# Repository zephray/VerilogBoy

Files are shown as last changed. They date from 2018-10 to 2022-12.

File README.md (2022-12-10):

VerilogBoy
==========

Coding for fun - the hard way. Trying to implement a Game Boy® compatible machine with Verilog.

This project is an open source Game Boy® compatible console Verilog RTL implementation.

# System Architecture

The main system architecture is designed as follows (outdated):

Architecture

There are three major parts needs to be implemented: the Game Boy CPU (8-bit CISC Processor called SM83, Intel 8080 like), the PPU (Pixel Processing Unit), and the sound unit (sometimes referred as a PSG, Programmable Sound Generator). Several interfacing modules are needed to support the IO capability provided by the hardware (such as an FPGA development board).

# Targets (Ports)

Current Pano Logic G1 is the only supported platform.

# Progress

Refactoring in progress. Current version could run several commerical games with no noticable glitch on the Pano Logic G1 device. 'Master' branch contains the previous version that runs on the ML505.

 - [x] SM83 CPU (Refactoring stage 1 done, passes all Blargg's tests)
 - [x] PPU (Pixel Processing Unit, Pixel-FIFO architecture)
 - [x] OAMDMA (Object Attribute Memory DMA)
 - [x] PSG (Programmable Sound Generator)
 - [x] Timer
 - [x] Link (Dummy link module, allows some games to run in single player mode)

Next step would be improving the accuracy.

Photo of VerilogBoy on Pano G1 running open source GameBoy game [Tobu Tobu Girl](http://tangramgames.dk/tobutobugirl/):

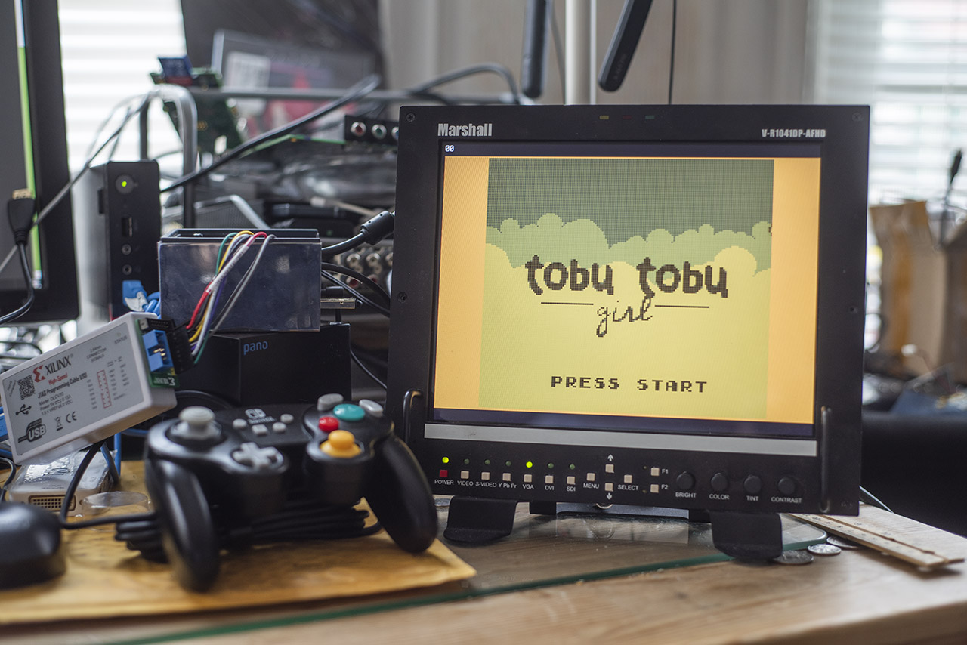
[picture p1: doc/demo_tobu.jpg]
Running-on-PanoG1


For progress regarding different ports, view README.md under the specific target folder.

# Accuracy

This project is not built to be entirely accurate, but built with accuracy in mind. Most of the CPU timing should follow the original DMG-CPU, and implement a rudimentary 2-stage pipelining just as the original one does. 

Here are the results of several tests I have tried to run on it.

PPU implementation is ... wrong: There are two pipelines in the GameBoy PPU, one for BG and one for sprite. I only implemented one for both. There is only one fetcher, though.

Note: Tests which depends on the revision / model of GameBoy are omitted. VerilogBoy only focus on behaviors that are common among all monochrome GameBoys (GS).

## Blargg's tests

| Test | mooneye-gb | BGB  | Gambatte | Higan | MESS | VerilogBoy |
| --- | --- | ---- | --- | ----- | ---- |---|
| cpu instrs | :+1: | :+1: | :+1: | :+1:  | :+1: | :+1: |

Notes: other tests hasn't been tried.

## Mooneye GB acceptance tests

| Test | mooneye-gb | BGB  | Gambatte | Higan  | MESS | VerilogBoy |
| --- | --- | ---- | --- | --- | ---- |---|
| add sp e timing | :+1: | :x:  | :+1: | :+1: | :+1: | :+1: |
| call timing | :+1: | :x:  | :+1: | :+1: | :+1: | :+1: |
| call timing2 | :+1: | :x:  | :+1: | :+1: | :+1: | :+1: |
| call cc_timing | :+1: | :x:  | :+1: | :+1: | :+1: | :+1: |
| call cc_timing2 | :+1: | :x:  | :+1: | :+1: | :+1: | :+1: |
| di timing GS | :+1: | :+1: | :+1: | :+1: | :+1: | :+1: |
| div timing | :+1: | :+1: | :+1: | :+1: | :+1: | :+1: |
| ei sequence | :+1: | :+1: | :+1: | :+1: | :x:  | :+1: |
| ei timing | :+1: | :+1: | :+1: | :+1: | :+1: | :+1: |
| halt ime0 ei | :+1: | :+1: | :+1: | :+1: | :+1: | :+1: |
| halt ime0 nointr_timing | :+1: | :+1: | :+1: | :+1: | :+1: | :+1: |
| halt ime1 timing | :+1: | :+1: | :+1: | :+1: | :+1: | :+1: |
| halt ime1 timing2 GS | :+1: | :+1: | :+1: | :+1: | :+1: | :+1: |
| if ie registers | :+1: | :+1: | :+1: | :+1: | :+1: | :+1: |
| intr timing | :+1: | :+1: | :+1: | :+1: | :+1: | :+1: |
| jp timing | :+1: | :x:  | :+1: | :+1: | :+1: | :+1: |
| jp cc timing | :+1: | :x:  | :+1: | :+1: | :+1: | :+1: |
| ld hl sp e timing | :+1: | :x:  | :+1: | :+1: | :+1: | :+1: |
| oam dma_restart | :+1: | :x:  | :+1: | :+1: | :+1: | :+1: |
| oam dma start | :+1: | :x:  | :+1: | :+1: | :+1: | :+1: |
| oam dma timing | :+1: | :x:  | :+1: | :+1: | :+1: | :+1: |
| pop timing | :+1: | :x:  | :+1: | :+1: | :+1: | :+1: |
| push timing | :+1: | :x:  | :x: | :+1: | :+1: | :+1: |
| rapid di ei | :+1: | :+1: | :+1: | :+1: | :+1: | :+1: |
| ret timing | :+1: | :x:  | :+1: | :+1: | :+1: | :+1: |
| ret cc timing | :+1: | :x:  | :+1: | :+1: | :+1: | :+1: |
| reti timing | :+1: | :x:  | :+1: | :+1: | :+1: | :+1: |
| reti intr timing | :+1: | :+1: | :+1: | :+1: | :+1: | :+1: |
| rst timing | :+1: | :x:  | :x: | :+1: | :+1: | :+1: |

### Instructions

| Test | mooneye-gb | BGB  | Gambatte | Higan  | MESS | VerilogBoy |
| --- | --- | ---- | --- | --- | ---- |---|
| daa | :+1: | :+1: | :+1: | :+1: | :+1: | :+1: |

### Interrupt handling

| Test | mooneye-gb | BGB  | Gambatte | Higan  | MESS | VerilogBoy |
| --- | --- | ---- | --- | --- | ---- |---|
| ie push | :+1: | :x:  | :x: | :x: | :x:  | :+1: |

### OAM DMA

| Test | mooneye-gb | BGB  | Gambatte | Higan  | MESS | VerilogBoy |
| --- | --- | ---- | --- | --- | ---- |---|
| basic | :+1: | :+1: | :+1: | :+1: | :+1: | :+1: |
| reg_read | :+1: | :+1: | :+1: | :x: | :x:  | :+1: |
| sources dmgABCmgbS | :+1: | :+1: | :x: | :x: | :x:  | :x: |

### Serial

| Test | mooneye-gb | BGB  | Gambatte | Higan | MESS | VerilogBoy |
| --- | --- | ---- | --- | ---| ---- |---|
| boot sclk align dmgABCmgb | :x: | :+1: | :+1: | :x: | :x:  | :x: |

Note: this test only seems to test the time to finish the first transfer. What about the second? (Delta time required to do a transfer and get notified by the interrupt)

### PPU

| Test | mooneye-gb | BGB  | Gambatte | Higan | MESS | VerilogBoy |
| --- | --- | ---- | --- | ---| ---- |---|
| hblank ly scx timing GS | :+1: | :+1: | :x: | :x: | :+1: | :x: |
| intr 1 2 timing GS | :+1: | :+1: | :+1: | :+1:  | :+1: | :x: |
| intr 2 0 timing | :+1: | :+1: | :x: | :+1:  | :+1: | :x: |
| intr 2 mode0 timing | :+1: | :+1: | :x: | :x: | :+1: | :x: |
| intr 2 mode3 timing | :+1: | :+1: | :x: | :x: | :+1: | :x: |
| intr 2 oam ok timing | :+1: | :+1: | :x: | :x: | :+1: | :x: |
| intr 2 mode0 timing sprites | :x: | :+1: | :x: | :x: | :+1: | :x: |
| lcdon timing dmgABCmgbS | :x: | :+1: | :x: | :x: | :x:  | :x: |
| lcdon write timing GS | :x: | :+1: | :x: | :x: | :x:  | :x: |
| stat irq blocking | :x: | :+1: | :+1: | :x: | :+1: | :x: |
| stat lyc onoff | :x: | :+1: | :x: | :x: | :x:  | :x: |
| vblank stat intr GS | :+1: | :+1: | :x: | :+1:  | :+1: | :x: |

### Timer

| Test | mooneye-gb | BGB  | Gambatte | Higan  | MESS | VerilogBoy |
| --- | --- | ---- | --- | --- | ---- |---|
| div write | :+1: | :+1: | :x: | :+1: | :+1: | :+1: |
| rapid toggle | :+1: | :+1: | :x: | :x: | :+1: | :+1: |
| tim00 div trigger | :+1: | :+1: | :+1: | :x: | :+1: | :+1: |
| tim00 | :+1: | :+1: | :x: | :+1: | :+1: | :+1: |
| tim01 div trigger | :+1: | :+1: | :x: | :x: | :+1: | :+1: |
| tim01 | :+1: | :+1: | :+1: | :+1: | :+1: | :+1: |
| tim10 div trigger | :+1: | :+1: | :x: | :x: | :+1: | :+1: |
| tim10 | :+1: | :+1: | :x: | :+1: | :+1: | :+1: |
| tim11 div trigger | :+1: | :+1: | :x: | :x: | :+1: | :+1: |
| tim11 | :+1: | :+1: | :x: | :+1: | :+1: | :+1: |
| tima reload | :+1: | :+1: | :x: | :x: | :+1: | :+1: |
| tima write reloading | :+1: | :+1: | :x: | :x: | :+1: | :+1: |
| tma write reloading  | :+1: | :+1: | :x: | :x: | :+1: | :+1: |

# Directory Structure

Note: things that will be removed in the near future may not shown here. Not all source files are shown here.

```
.
├── doc                          -- Documents
│   ├── control_unit.ods           -- CPU control unit LUT
│   ├── cpu_internal.md            -- CPU internal signal encoding
│   └── cpu.md                     -- CPU design note
├── LICENSE                      -- OHDL
├── Makefile                     -- Toplevel Makefile
├── README.md                    -- This document
├── roms                         -- Place for platform independent ROMs
│   ├── bootrom.s                  -- Boot ROM
│   ├── Makefile                   -- Makefile for building the Boot ROM
│   └── tests                      -- Unit tests
│       ├── compare.sh               -- Script for comparing results between VBC and emulator
│       ├── dmg_emu.exe              -- Reference emulator
│       └── Makefile                 -- Makefile for running tests
├── rtl                          -- RTL files
│   ├── alu.v                      -- ALU
│   ├── boy.v                      -- VerilogBoy portable top level file
│   ├── brom.v                     -- Boot ROM
│   ├── common.v                   -- Common definitions
│   ├── control.v                  -- Control Unit
│   ├── cpu.v                      -- CPU top level
│   ├── dma.v                      -- OAM DMA
│   ├── Makefile                   -- Makefile for building the VBC using Verilator
│   ├── mbc5.v                     -- Cartridge paging, optional
│   ├── ppu.v                      -- Pixel Processing Unit
│   ├── regfile.v                  -- CPU Register file
│   ├── singleport_ram.v           -- Singleport RAM template
│   ├── singlereg.v                -- Singlebit register template
│   └── timer.v                    -- Timer
├── sim                          -- Simualtion
│   └── verilator                  -- Verilator-based simulator 
│       ├── dispsim.cpp              -- LCD simulator based on SDL 2.0
│       ├── Makefile                 -- Makefile for building the simulator
│       ├── mbcsim.cpp               -- MBC cartridge controller simulator
│       ├── memsim.cpp               -- Boot ROM or Game ROM simulator
│       ├── mmrprobe.cpp             -- Unit for dumping memory or MMR accesses
│       └── vb_sim.cpp               -- Simulator main file
├── target                       -- Targets (ports) of VBC
│   ├── panog1                     -- Pano Logic G1 devices
│   │   ├── fpga                     -- FPGA RTL
│   │   │   ├── dualport_ram.v         -- Template of dual port RAM
│   │   │   ├── idt_clkgen.v           -- Code for interfacing with clock generator
│   │   │   ├── mig                    -- LPDDR memory controller
│   │   │   ├── mig_picorv_bridge.v    -- Bridge for connecting PicoRV32 and LPDDR controller
│   │   │   ├── mig.ucf                -- Timing constraint for memory controller
│   │   │   ├── mobile_ddr.v           -- Simulation model for LPDDR
│   │   │   ├── panog1.xise            -- ISE project file
│   │   │   ├── pano_top.v             -- Top level HDL
│   │   │   ├── pano.ucf               -- Main pin location constraint
│   │   │   ├── picorv32.v             -- PicoRV32 RISC-V softcore
│   │   │   ├── picosoc_mem.v          -- PicoRV32 scratchpad memory
│   │   │   ├── simple_uart.v          -- Simple UART transmitter 
│   │   │   ├── testbench.v            -- Testbench with LPDDR model
│   │   │   ├── usb_picorv_bridge.v    -- Bridge for connecting PicoRV32 and USB controller
│   │   │   ├── vga_font.v             -- VGA font ROM
│   │   │   ├── vga_mixer.v            -- Mixing PicoRV32 and VerilogBoy image
│   │   │   └── vga_timing.v           -- VGA timing generator
│   │   ├── fw                       -- Firmware for RV softcore
│   │   │   ├── bootloader             -- Bootloader for loading firmware from SPI Flash
│   │   │   │   ├── bootloader.c         -- Main source code
│   │   │   │   ├── Makefile             -- Makefile for building the bootloader
│   │   │   │   ├── sections_bl.lds      -- Link script
│   │   │   │   └── start_bl.s           -- Startup code
│   │   │   ├── dhrystone              -- Dhrystone test for RV softcore
│   │   │   ├── firmware               -- Firmware for softcore
│   │   │   │   ├── COPYING              -- GPLv2 License for firmware
│   │   │   │   ├── firmware.c           -- Main source code 
│   │   │   │   ├── isp1760.c            -- ISP1760 HCD
│   │   │   │   ├── isp_roothub.h        -- RootHub emulation for HCD (optional)
│   │   │   │   ├── Makefile             -- Makefile for building the firmware
│   │   │   │   ├── misc.c               -- Delay and other common routines
│   │   │   │   ├── sections.lds         -- Link script
│   │   │   │   ├── syscalls.c           -- Syscalls for the newlib
│   │   │   │   ├── term.c               -- Simple virtual terminal
│   │   │   │   ├── usb.c                -- Host USB stack
│   │   │   │   ├── usb_gamepad.c        -- Generic USB HIB gamepad driver
│   │   │   │   └── usb_storage.c        -- USB mass storage driver
│   │   │   └── README.md              -- README about firmware
│   │   └── README.md                -- README about Pano Logic G1 port
│   └── vbh                        -- VerilogBoy Handheld
│       ├── fpga                     -- FPGA RTL
│       └── fw                       -- Firmware for on-board MCU
└── tools                        -- Tools for building things
    ├── bin2mif                    -- Convert binary blob to mif
    └── vga_timing.xlsx            -- Tool for calculating VGA timing
```

# How to use

## Verilator-based simulator

Tested environment: Ubuntu 20.04 LTS, mac OS Big Sur. 

Dependencies: build-essential, verilator, libsdl2-dev, wine(optional, for unit test only, for now), rgbds(not available from apt, need build manually).

On Debian/ Ubuntu, do the following:

```
sudo apt install build-essential verilator libsdl2-dev wine byacc flex pkg-config libpng-dev
```

On macOS, do the following:

```
brew install verilator sdl2 pkg-config libpng
```

To install rgbds:

```
git clone https://github.com/rednex/rgbds
cd rgbds
make
make install
```

### Build

At project directory:
```
make
```

Copy the bootrom.mif to where it is required. (For example, target/panog1)

### Running unit-tests

At project directory:
```
cd roms/tests
make
./compare.sh
```

### Running ROMs

At project directory:
```
./sim/verilator/vb_sim <path_to_your_rom.gb> --mbc --nostop
```

Few parameters:
```
--nostop: Don't stop execution at halt/stop (but stop at illegal instructions)
--trace: Generate vcd waveform trace
--testmode: Disable internal Boot ROM, headless mode, limit cycles to 32K.
--noboot: Disable internal Boot ROM, code execution starts at 0x0000 rather than 0x0100.
--verbose: Enable debug output
--mbc: Enable MBC1/3/5 emulation for ROMs larger than 32KB
```

## FPGA targets

See README inside target directory.

# Acknowledge

This project reused codes from several other projects. A great thanks to their efforts!

 - [https://github.com/nightslide7/Gameboy](https://github.com/nightslide7/Gameboy)
 - [https://github.com/cliffordwolf/picorv32](https://github.com/cliffordwolf/picorv32)
 - [https://github.com/u-boot/u-boot](https://github.com/u-boot/u-boot)
 - [https://github.com/twlostow/dsi-shield](https://github.com/twlostow/dsi-shield)
 - [https://github.com/MParygin/v.vga.font8x16](https://github.com/MParygin/v.vga.font8x16)

These projects are used as references. Again, thanks for sharing.

 - [https://github.com/freecores/genesys_ddr2](https://github.com/freecores/genesys_ddr2)
 - [https://github.com/ZipCPU/s6soc](https://github.com/ZipCPU/s6soc)

These are extremely helpful resources about the Game Boy® itself:

 - [https://github.com/Gekkio/mooneye-gb](https://github.com/Gekkio/gb-ctr)
 - [https://github.com/Gekkio/gb-ctr](https://github.com/Gekkio/gb-ctr)

Game used for demonstration, thanks for the great game:

 - [https://github.com/SimonLarsen/tobutobugirl](https://github.com/SimonLarsen/tobutobugirl)

# Legalese

I'm not affiliated with Nintendo in any way. Game Boy® is a registered trademark by Nintendo. Nintendo® is a registered trademark. All other trademarks are property of their respective owner.

# License

The dsicore is made by twlostow, released under LGPL 3.0.

The PicoRV32 is free and open hardware licensed under the [ISC license](http://en.wikipedia.org/wiki/ISC_license)
(a license that is similar in terms to the MIT license or the 2-clause BSD license).

Some firmware code of pano-g1 target are released to public domain.

All other software codes (including simulation code) are licensed under MIT.

All other HDL codes are licensed under OHDL 1.0.

All other text documents are licensed under CC BY-SA 4.0

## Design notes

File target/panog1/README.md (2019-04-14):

VerilogBoy for Pano Logic G1
============================

## Overview

From https://tomverbeure.github.io/rtl/2018/11/26/Racing-the-Beam-Ray-Tracer.html#the-hw-platform:

> Pano Logic was a Bay Area startup that wanted to get rid of PCs in large organizations by replacing them with tiny CPU-less thin clients that were connected to a central server. Think of them as VNC replacements. No CPU? No software upgrades! No virusses!
> 
> The thin clients had a wired Ethernet interface, a couple of USB ports, an audio port and a video port.
> All this was glued together with an FPGA.
> 
> The company has been defunct since 2013 and the clients are not supported by anything. But they are amazing for hobby purposes and can be bought dirt cheap on eBay.
> 
> There are 2 versions: the first one has a VGA video interface, later versions have a DVI port.
> 
> The VGA version uses the Xilinx Spartan-3E 1600. The DVI version a very powerful Spartan-6 LX150.

This port focus on the VGA version (3E-1600).

## Status

Working in Progress. Preview version available in the GitHub 'Releases' section.

## Components

### LPDDR controller

Based on Xilinx MIG, LPDDR-200 @ 16-bits.

Details available at hackaday: [A detour to the Pano Logic G1 (1) - LPDDR](https://hackaday.io/project/57660/log/159790-a-detour-to-the-pano-logic-g1-1-lpddr)

Used to be a memory cache between PicoRV32 and LPDDR, now as code is XIP from Flash, cache is move to flash. All access to LPDDR is non cached.

### PicoRV32 soft-processor

PicoRV32 is a RISC-V compatible soft-processor written by Clifford Wolf: https://github.com/cliffordwolf/picorv32.

Configured as RV32IC, running at 25MHz.

Currently, code is XIP from SPI Flash. SPI Flash also runs at 25MHz (Maximum frequency of M25P80 is 75MHz), 1 bit mode. A 4KB 2-way set associative cache is added between the PicoRV32 and SPI IF. Expect very poor performance.

The PicoRV32 uses in total 8 BRAM18K for memories, 4 as scratchpad memory (8KB), 2 as I-cache (4KB), 2 as video RAM (4KB).

## Building

A modern Linux environment is required to build the firmware for the PicoRV32 soft processor. ISE version 14.7 is required to build the bitstream for the FPGA, WebPACK version is fine. ISE doesn't need to be installed on the Linux, it can be installed on a sepearate Windows machine, or inside a virtual machine.

### Firmware

Follow the instruction in the [PicoRV32 repository](https://github.com/cliffordwolf/picorv32) to install the riscv32ic toolchain.

Cd into target/panog1/fw/firmware, run '''make'''. The firmware.bin is the target firmware.

### BootROM

A boot ROM is required to boot the VerilogBoy Core. Skip if you are not going to play GB games on it.

[rgbds](https://github.com/rednex/rgbds) is required to build the boot ROM. Follow the instruction to install it.

Cd into roms, run '''make'''. The bootrom.mif is the target firmware. Copy the file into target/panog1/fpga.

### Bitstream

Open target/panog1/fpga/panog1.xise using ISE, double click 'Generate Programming File', the pano_top.bit is the target bitstream.

### Flash Image

1. Open iMPACT, create a new project, and double click 'Create PROM File' on the left. 
2. Select 'Configure Single FPGA' under 'SPI Flash' on the left. Click the right arrow button.
3. Select '8M' as 'Storage Device (bits)', click 'Add Storage Device', and then click the right arrow button.
4. Enter a file name, set 'Add Non-Configuration Data Files' to 'Yes'. Click 'OK'.
5. Select the bitstream file. 
6. When asked to add another device file, select 'No'.
7. When asked to add data file, select 'Yes'
8. Enter 'c0000' as the start address.
9. Choose the 'firmware.bin'. (Not 'firmware.elf'!)
10. Double click 'Generate File' on the left.
11. Now the target mcs file should be generated. Flash it into the FPGA use iMPACT.

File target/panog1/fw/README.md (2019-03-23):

Firmware for Pano Logic G1
==========================

# How to use

Type '''make''' to build the firmware. Depending on the type, it may either generate a .bin file (to be flashed into SPI Flash) or some .mif file (to be loaded into Block RAM). For the .bin file, generate and flash the .mcs image use iMPACT. For the .mif file, copy over to ../fpga and rebuild the FPGA project.

# What's here

 - bootloader: Initialize the LPDDR, do a simple memory check, and copy the content from SPI Flash into LPDDR then jump to the LPDDR.
 - dhrystone: Dhrystone test, to be executed inside LPDDR. (Or withsome modification, inside BlockRAM). Typical performance inside LPDDR: 0.25 DMIPS/MHz.
 - firmware: Main firmware to be used in the project.

Generally you want to use the bootloader and the firmware.

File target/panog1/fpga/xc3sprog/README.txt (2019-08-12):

This dir contains simple cores to access the internal SPI-flash via BSCAN/USER1.

The bitfiles are provided for your convenience.

All IOBs are unused and set to float.
The config + JTAG pins have their default pull-up/downs enabled. 
You have to make your own bitstream if you don't like that.

The Spartan-3E Starterkit (ug320.pdf) can have a lot of possible
contentions. So BSCAN_SPI needs some more Pins set to work. Often the first
run with the -I option still fails. The kit also fails to reboot after some
-I run has been done.

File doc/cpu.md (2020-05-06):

# CPU

The Game Boy® is powered by a 8-bit Intel 8080-like CISC processor. It is usually called as "GB-Z80", however, it is not a Z80 compatible processor, nor a 8080 compatible processor. This page is not a full document of the original GameBoy processor, but some brief description of the processor and some of my own understanding. The information in this page may or may not be correct.

For a comprehensive and more reliable documentation of GB CPU, see https://github.com/Gekkio/gb-ctr.

## Registers

The Game Boy CPU have one bank of general purpose 8-bit registers:

* B
* C
* D
* E
* H
* L

These 8-bit registers may be accessed as 16-bit registers:

* BC
* DE
* HL

There are two SF 8-bit registers:

* A - Accumulator
* F - Flags

There are 4 usable flags in the flags register, all other bits are 0:

* 7 - Z (Zero)
* 6 - N (Substract)
* 5 - H (Half Carry)
* 4 - C (Carry)

There are also two SF 16-bit registers:

* PC - Program Counter
* SP - Stack Pointer

Since the PC is 16-bit, SP should always be 16-bit aligned. SP always point to last used stack slot. Means that the first slot should be always empty.

Note, though there are 16-bit register, and the 8-bit register may be accessed in the 16-bit manner, the internal datapath is limited to 8-bit, means it could not finish 16-bit data transfer in one cycle. These are solely for addressing.

## Instructions

Instruction length can be 1 - 4 bytes long depending on the specific instruction. Opcodes can be seen as 9 bits long, and will be encoded into 1 or 2 bytes. If the first byte is 0xCB, then the second byte would be one of the high 256 opcodes, otherwise, the first byte is one of the low 256 opcodes. 

For example, if the first byte is 0x43, then the opcode of this instruction is 0x043; if the first byte is 0xCB and the next byte is the 0x43, then the opcode of this instruction is 0x143.

After the opcode, there can be a optional immediate, 8-bit or 16-bit long, gives the total length of 1 - 4 bytes.

## Execution Timing

The processor runs at either 4 MiHz (4194304 Hz = 2^12 Hz) or 8 MiHz (Double Speed Mode on GBC). The instruction execution time is always dividable by 4, ranging from 4 cycles to 20 cycles. Ususally a clock cycle at 4 MiHz is called a T-cycle. 4 T-cycles combined together is called a M-cycle (1 MiHz). So, one instruction could take 1 - 5 M-cycles to execute. 

The processor can do one memory read or memory write in one M-cycle, since the instruction itself needed be fetched, the execution speed can never be faster than the speed it can read the instruction. For example, a 3 byte instruction needs at least 3 M-cycles (12 T-cycles) to execute. If the instruction involves memory read or write, the processor would have to spend more M-cycles just to access the memory. 

The processor is also only capable of doing 1 8-bit ALU operation each M-cycle, if the instruction need to do 16-bit ALU operation, additional 1 M-cycle may be needed to complete the operation.

The processor also has a prefetch queue with the length of 1 byte.

## Bus Timing

The GB CPU has one 8080 bus compatible bus. The bus supports only memory access, not IO access. All the ROM, RAM, and MMIO peripherals are on the same bus. Here is a timing diagram:

```text
            |  1  |  2  |  3  |  4  |
          ___________             _____            
CLK  ____|           |___________|     
    __    __    __    __    __    __    
CK    |__|  |__|  |__|  |__|  |__|  |__
    ___________                   _____
CS             |_________________|
             ____________________
RD  ________|                    |_____
    _________________       ___________
WR                   |_____|
     _______ _______________________ __
ADDR _______X_______________________X__
                      _____
DATA ----------------<_____>-----------
```

CLK: 1 MiHz Bus Reference Clock
CK:  4 MiHz Internal Clock (need to verify the phase)
ADDR: Address Bus
CS, RAM Access Enable, Low Active
RD: Read Enable, Low Active
WR, Write Enable, Low Active

Note: See GB-CTR for more information.

## Instructions

## Common Encodings

### 16bit Reg addressing encoding 1 (e_ad1)
* 2'b00: BC
* 2'b01: DE
* 2'b10: HL
* 2'b11: SP

### 16bit Reg addressing encoding 2 (e_ad2)
* 2'b00: BC
* 2'b01: DE
* 2'b10: HL+
* 2'b11: HL-

### 16bit Reg addressing encoding 3 (e_ad3)
* 2'b00: BC
* 2'b01: DE
* 2'b10: HL
* 2'b11: AF

### 8bit Reg addressing encoding 1 (e_ab1)
* 3'b000: B
* 3'b001: C
* 3'b010: D
* 3'b011: E
* 3'b100: H
* 3'b101: L
* 3'b110: databus
* 3'b111: A

### 8bit Reg addressing encoding 2 (e_ab2)
* e_ab1 with LSB moved to MSB (021)

### ALU operations (e_alu)
* 3'b000 ADD
* 3'b001 ADC
* 3'b010 SUB
* 3'b011 SBC
* 3'b100 AND
* 3'b101 XOR
* 3'b110 OR
* 3'b111 CP

### Special ALU operations (e_alu_sp)
* 2'b00 DAA
* 2'b01 CPL
* 2'b10 SCF
* 2'b11 CCF

### Bitwise ALU operations part 1 (e_alu_b1)
* 3'b000 RLC
* 3'b001 RRC
* 3'b010 RL
* 3'b011 RR
* 3'b100 SLA
* 3'b101 SRA
* 3'b110 SWAP
* 3'b111 SRL

### Bitwise ALU operations part 2 (e_alu_b2)

* 2'b00 Used by other opcodes
* 2'b01 BIT
* 2'b10 RES
* 2'b11 SET

## Load SP to Immediate Address

* LD (a16), SP
* 3 bytes long
* 5 M-cycles to execute
* No flags shall be altered
* 8'b00001000

## Load 16bit immediate to 16bit register

* LD rr, d16
* 3 bytes long
* 3 M-cycles to execute
* No flags shall be altered
* 8'b00rr0001
* Use e_ad1 for rr encoding

## Load Register to Memory

* LD (rr), A
* 1 byte long
* 2 M-cycles to execute
* No flags shall be altered
* If self increment/decrement is involved, it should happen after the access
* 8'b00dd0010
* Use e_ad2 for rr encoding

## Load 8bit Immediate to 8bit Register/ to Memory

* LD r, d8 / LD (HL), d8
* 2 bytes long
* 2 (reg)/ 3 (mem) M-cycles to execute
* No flags shall be altered
* 8'b00rrr110
* Use e_ab2 for rrr encoding

## Load Memory to Register

* LD A, (rr)
* 8'b00dd1010
* Otherwise the same as load reg to mem

## Load 8bit Register to 8bit Register/ to/ from Memory

* LD rd, rs
* 1 byte long
* 1 (reg)/ 2 (mem) M-cycles to execute
* No flags shall be altered
* 8'b01dddsss
* Use e_ab1 for ddd encoding
* Use e_ab1 for sss encoding
* Note that LD (HL), (HL) is impossible, it is replaced by HALT

## 16bit Register Self Increment/ Decrement

* INC dd / DEC dd
* 1 byte long
* 2 M-cycles to execute
* No flags shall be altered
* 8'b00dd0011 (INC) / 8'b00dd1011 (DEC)
* Use e_ad1 for dd encoding

## 8bit Register/ Memory Self Increment/ Decrement

* INC d / DEC d / INC (HL) / DEC (HL)
* 1 byte long
* 1 (reg)/ 3 (mem) M-cycles to execute
* Zero, Substract, and Half-Carry flag are altered
* 8'b00ddd100 (INC) / 8'b00ddd101 (DEC)
* Use e_ab2 for ddd encoding

## 8bit ALU Operations

* ADD r / ADC r / SUB r / SBC r / AND r / XOR r / OR r / CP r
* 1 byte (reg/mem) / 2 (imm) long
* 1 (reg) / 2 (mem) / 2 (imm) M-cycles to execute
* Flags depending on operation
* 8'b1iaaarrr
* i: 0 - Read from (HL), 1 - Use immediate value
* Use e_alu for aaa encoding
* Use e_ab1 for rrr encoding

## 8bit Special ALU Operations

* DAA / SCF / CPL / CCF
* 1 byte long
* 1 M-cycle to execute
* Flag depends
* 8'b001ss1111
* Use e_alu_sp for ss encoding

## 8bit Bitwise ALU Operations Part 1

* RLC r / RRC r / RL r / RR r / SLA r / SRA r / SWAP r / SRL r
* 1 byte long (not include CB)
* 1 (reg) / 3 (mem) to execute
* Flag depends
* 8'b00bbbrrr
* Use e_alu_b1 for bbb encoding
* Use e_ab1 for rrr encoding

## 8bit Bitwise ALU Operations Part 2

* BIT n, r / RES n, r / SET n, r
* 1 byte long (not include CB)
* 1 (reg) / 2 (memwb) / 3 (memtest) to execute
* Flags depends
* 8'bccnnnrrr
* Use e_alu_b2 for cc encoding
* Use e_ab1 for rrr encoding

## Microarchitecture

Note: This is NOT the microarchitecture of the GameBoy CPU, but that of the VerilogBoy CPU. It is a non-pipelined multi-cycle CISC core with hardwired control logic. To optimize the resource usage, the first stage decoding is actually a 256 entries LUT.

BCDEHLSP are in the register file, while A, F, and PC are not.

One M-cycle is 4 T-cycle. 

### CT-FSM

CT-FSM is a FSM running with the main 4 MiHz clock. It takes care of all the bus operations and instruction execution. It has 4 states,  always executed in a loop, from S0 to S3. To be clear, I am describing it from 2 perspectives: bus operation and instruction execution.

Bus Operation:

* S0: High Page access from last M-cycle
* S1: Setup Address
* S2: Wait
* S3: Setup Data for write cycle, Latch data for read cycle 

Instruction Execution:

* S0: Decoding & Execution
* S1: Register Write Back
* S2: PC Increment Cycle 1 / SP Operation Cycle 1
* S3: PC Increment Cycle 2 / SP Operation Cycle 2

### EX-FSM

EX-FSM is a FSM running only in S0 state in CT-FSM. The reason of having this FSM is that the CPU might need multiple M cycles to finish the execution of a single instruction, the FSM would keep track of which cycle it is in. Means the state of this FSM should always match the M cycle number.

If the instruction finishes this cycle, next cycle would be S0.

Main tasks of this FSM:
pc_wr
* Determine if this M-cycle would be memory write, memory read, or instruction fetch.
* Determine the input numbers of the ALU.
* Determine if the output of ALU should be write back to register.
* Determine if PC needs to be incremented.

Example:

ADD A, B, 1 cycle operation
During M0 - S1, EX-FSM instruct ALU OpA to be A, ALU OpB to be B, ALU Res WB En.

ADD A, (HL), 2 cycle operation

During M0 - S1, EX-FSM instruct ALU OpA to be A, ALU OpB to be Data Bus, ALU Res WB NEN, HL output to be next cycle ABUS Src, next state is S2

During M1 - S2, EX-FSM instruct ALU Res WB EN, PC output to be next cycle ABUS Src, next state is S1

```
       -----------             -----------             -----------             -----------             -----------
   ___|           |___________|           |___________|           |___________|           |___________|
      ^ S3 - Instr Fetch      ^ S0 - Control Unit     ^ S1 - Output PC low    ^ S2 - Output PC high   ^ S3 - ALU Free
                                                      ^ S1 - Output Last PC
                                                      ^ S1 - Register WB      ^ PC low WB             ^ PC high WB
```

JR:
Cycle 0: Fetch PC (JR); Calculate PC + 1
Cycle 1: JR execution, Fetching PC + 1, PC + 2 interrupted.
Cycle 2: r ready, calculate PC + r low byte
Cycle 3: calculate PC + r high byte, save to PC, and output to bus (!!!)

PUSH:
Cycle 0: Fetch PC (PUSH); Calculate PC + 1
Cycle 1: ALU: Nothing. No bus op. PC + 1 circuit use to calculate SP - 1
Cycle 2: ALU: Fetch B; DATA from Regfile; PC + 1 circuit use to calculate SP - 1
Cycle 3: ALU: Fetch C; DATA from Regfile; PC + 1 stopped.
Cycle 4: PC + 2 calculated; Fetch PC + 1;

POP:
Cycle 0: Fetch PC (POP), Calculate PC + 1
Cycle 1: ALU: Nothing. DATA Read from SP. PC + 1 circuit use to calculate SP + 1
Cycle 2: ALU: Data buffer to B; Data Read from SP. PC + 1 circuit use to calculate SP + 1
Cycle 3: ALU: Data buffer to C; Fetch PC + 1; Calculate PC + 1

LD (nn), A:
Cycle 0: Fetch PC, Calculate PC + 1
Cycle 1: ALU do nothing. Fetch PC + 1 (Imm), Calculate PC + 1
Cycle 2: ALU do nothing. Fetch PC + 1 (Imm), Stop PC calculation.
Cycle 3: ALU do nothing. Data write from A to TEMP. Stop PC calculation.
Cycle 4: ALU do nothing. Fetch PC + 1; Calculate PC + 1;

LD (nn), SP:
Cycle 0: Fetch PC, Calculate PC + 1
Cycle 1: ALU do nothing. Fetch PC + 1 (Imm), Calculate PC + 1
Cycle 2: ALU do nothing. Fetch PC + 1 (Imm), Stop PC calculation.
Cycle 3: ALU do nothing. Addr from Imm, Data write from SP to bus. Calculate Imm + 1
Cycle 4: ALU do nothing. Addr from Imm, Data write from SP to bus. 
Cycle 5: ALU do nothing. Fetch PC + 1; Calculate PC + 1;

LD A, (nn):
Cycle 0: Fetch PC, Calculate PC + 1
Cycle 1: ALU do nothing. Fetch PC + 1 (Imm), Calculate PC + 1
Cycle 2: ALU do nothing. Fetch PC + 1 (Imm), Stop PC calculation.
Cycle 3: ALU do nothing. Data read from TEMP. Stop PC calculation.
Cycle 4: ALU store data buffer to A. Fetch PC + 1; Calculate PC + 1;

RST:
Cycle 0: Fetch PC, Calculate PC + 1
Cycle 1: ALU: PCl to DB. No bus op. PC + 1 circuit use to calculate SP - 1
Cycle 2: ALU: PCh to DB; DATA from PCl to SP; PC + 1 circuit use to calculate SP - 1
Cycle 3: ALU: 16bit PC from Opcode; DATA from PCh to SP; Stop PC calculation.
Cycle 4: Fetch new PC; Calculate PC + 1

CALL nn:
Cycle 0: Fetch PC, Calculate PC + 1
Cycle 1: ALU do nothing. Fetch PC + 1 (Imm), Stop PC calculation.
Cycle 2: ALU do nothing. Fetch PC + 1 (Imm), Stop PC calculation.
Cycle 3: ALU: Nothing. No bus op. PC + 1 circuit use to calculate SP - 1
Cycle 4: ALU: Nothing; DATA from PCh to SP; PC + 1 circuit use to calculate SP - 1
Cycle 5: ALU: 16bit PC from Temp; DATA from PCl to SP; Stop PC calculation.
Cycle 6: Fetch new PC; Calculate PC + 1

RET:
Cycle 0: Fetch PC, Calculate PC + 1
Cycle 1: ALU: Nothing. Read SP. PC + 1 circuit use to calculate SP + 1
Cycle 2: ALU: Copy from Databus to PCl; Read SP + 1; PC + 1 circuit use to calculate SP + 1
Cycle 3: ALU: Copy from Databus to PCh; Databus no op. Stop PC calculation.
Cycle 4: Fetch new PC; Calculate PC + 1

RET cc:
Cycle 0: Fetch PC, Calculate PC + 1
Cycle 1: Check condition and decide if need to continue
Cycle 2: If taken, same as ret start from Cycle 1; If not, fetch new PC; Calculate PC + 1

## Interrupt

The interrupt check happens at the same time as the instruction fetch (S3). If there is an interrupt, the normal execution would be stopped, and the instruction fetch for the ISR would happen at the fifth M cycle:

Cycle 0: During normal PC fetch and PC+1 calculation, interrupt happend, dispatch scheduled.
Cycle 1: Calculate SP - 1. Bus no op.
Cycle 2: Calculate SP - 1. Bus write PCh.
Cycle 3: No calculate. Bus write PCl. Check interrupt source, decide which to dispatch
Cycle 4: Fetch first byte of ISR
Cycle 5: Start ISR execution

## Reference

* http://www.pastraiser.com/cpu/gameboy/gameboy_opcodes.html
* http://sgate.emt.bme.hu/patai/publications/z80guide/app1a.html
* http://www.devrs.com/gb/files/GBCPU_Instr.html
* https://github.com/Gekkio/mooneye-gb/blob/master/docs/accuracy.markdown
* https://gekkio.fi/files/gb-docs/gbctr.pdf

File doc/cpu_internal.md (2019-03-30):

# CPU Control Unit Signals

## alu_src_a

Select ALU Operand 1 source:

00 - A register
01 - PC byte
10 - Register file
11 - Databus buffer

## alu_src_b

Select ALU Operand 2 source:

000 - A register
001 - Carry bit
010 - Constant 0
011 - Constant 1
100 - H register
101 - L register
110 - Absolute Imm Low
111 - Imm Low

## alu_op_prefix

Prepend to alu_op_mux

00 - Normal ALU operations
01 - Shift&Rotate ALU operations
10 - Special ALU operations
11 - CB prefix ALU operations

## alu_op_src

Selection source of alu_op

00 - Instruction[5:3]
01 - {1'b1, Instruction[7:6]}
10 - Fixed ADD ; F to result
11 - Fixed SUB ; A to F

# alu_op_signed

Force signed operation

## alu_dst

Selection of destination of ALU.
00 - A register
01 - PC byte
10 - Register file 
11 - Databus buffer

## pc_src

16-bit PC write source

00 - Register file
01 - {10'b00, Instruction[7:6], Instruction[3], 3'b000}
10 - temp register
11 - 

## pc_we

16-bit PC write enable (from register file)

## pc_b_sel

Cycle 0, 2, 4 select PCl
Cycle 1, 3, 5 select PCh
This could not be overrided

## rf_wr_sel

Register file write target selection.

000 - B / BC
001 - C
010 - D / DE
011 - E
100 - H / HL
101 - L
110 - SP High / SP
111 - SP Low

## rf_rd_sel

Register file read source selection.

## bus_op

00 - Idle cycle
01 - Instruction Fetch
10 - Write cycle
11 - Read cycle (Imm or Data)

## db_src

00 - A register
01 - ALU result
10 - Register file
11 - Databus Buffer

## ab_src

00 - PC register
01 - temp register
10 - Register file 16bit read out
11 - SP register

## ct_op

Operation of CT-FSM at this M-cycle.

00 - Nothing
01 - PC + 1
10 - SP - 1
11 - SP + 1

## temp_redir

Redirect regfile operation to temp register

0 - Normal
1 - Redir

## opcode_redir

Redirect opcode read to temp register (for 0xCB)

0 - Normal
1 - Redir

## flags_we

Will the flag being written to F register?

0 - No
1 - Yes

## flags_pattern

00 - Z N H C
01 - - 0 H C
10 - 0 0 H C
11 - Z N H -

## next

Does this instruction end at this cycle

## int_master_en

The global interrupt enable flag is handled inside the control unit. This signal is the current enable flag status from control unit.

## int_dispatch

The flag to control unit indicating if the interrupt dispatch is ongoing.

## int_ack

The flag from control unit indicating that the dispatching is finished and the dispatch flag should be cleared.

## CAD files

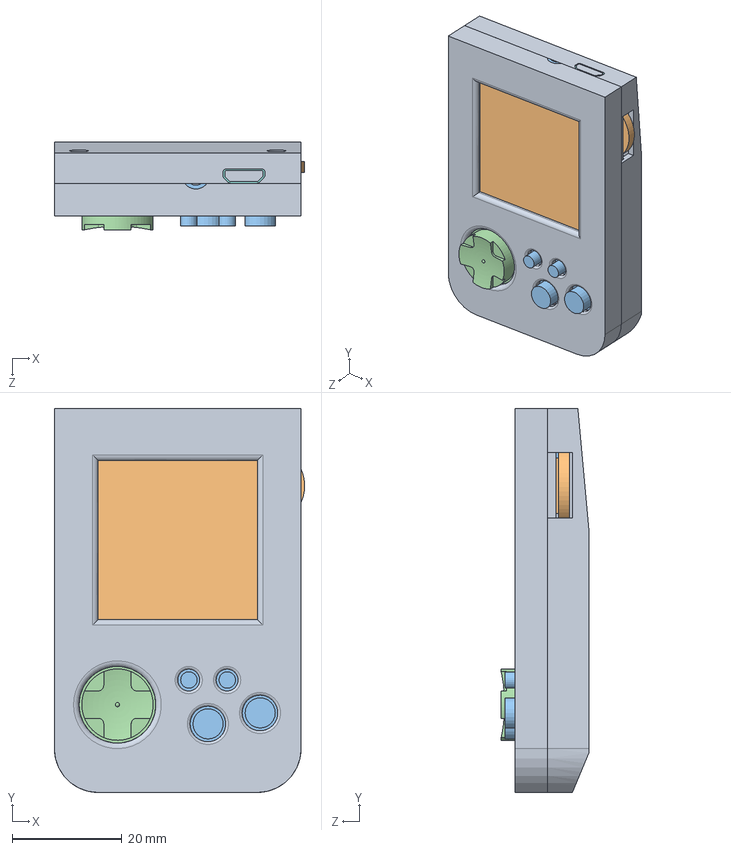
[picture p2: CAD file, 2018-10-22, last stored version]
hardware/3d_models/assembly.SLDASM
45.6 x 70.0 x 16.0 mm
front_case
lcd
key_foam
dpad
pcb
bp_6m
HY-TF1007B
USBMicroF
back_case
siq-02fvs3
PJ-327F
bc-15-3p
label

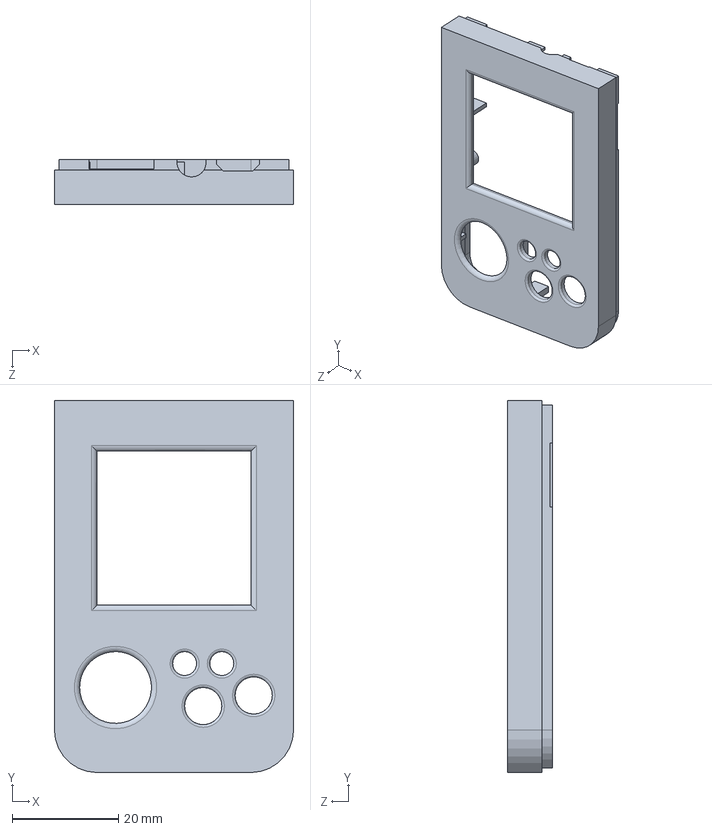
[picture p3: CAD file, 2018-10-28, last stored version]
hardware/3d_models/front_case.SLDPRT
45.0 x 70.0 x 8.50 mm

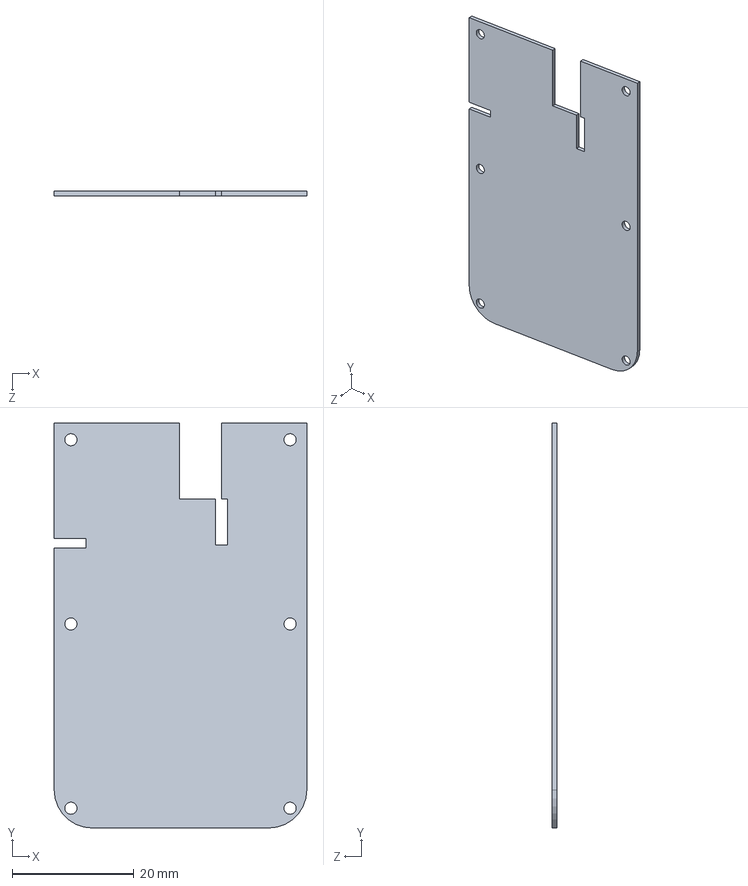
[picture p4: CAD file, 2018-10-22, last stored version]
hardware/3d_models/pcb.SLDPRT
41.5 x 66.5 x 0.8 mm

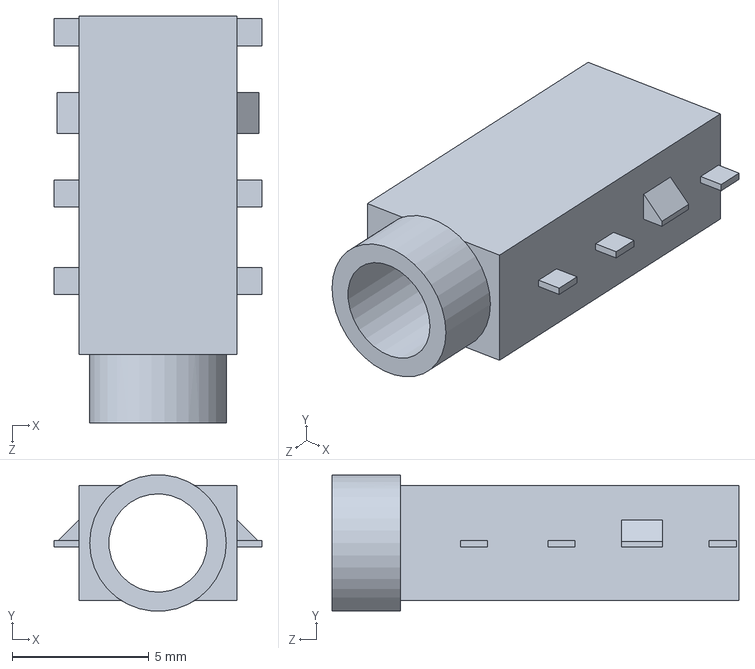
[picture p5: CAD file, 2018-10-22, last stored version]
hardware/3d_models/PJ-399B.SLDPRT
7.60 x 4.98 x 14.9 mm

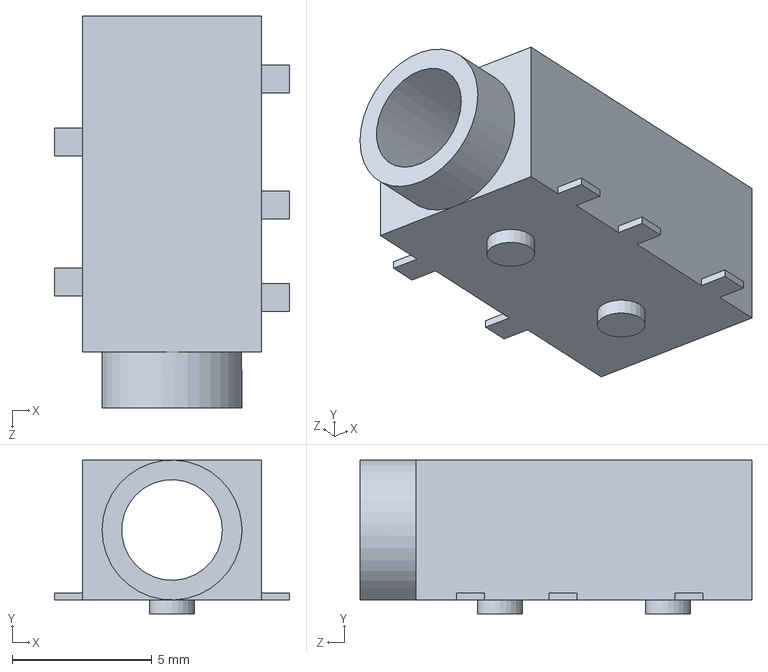
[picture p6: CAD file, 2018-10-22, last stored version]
hardware/3d_models/PJ-327F.SLDPRT
8.40 x 5.50 x 14.0 mm

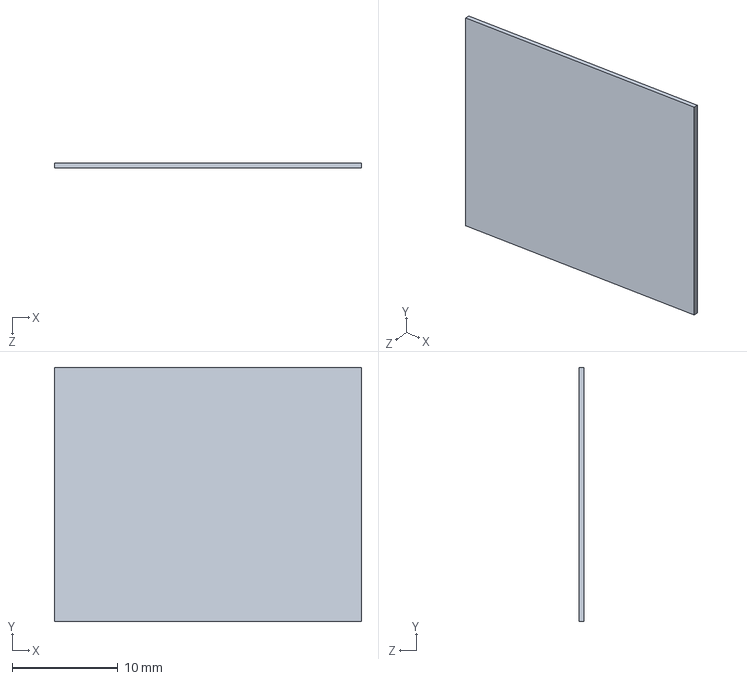
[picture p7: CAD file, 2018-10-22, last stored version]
hardware/3d_models/label.SLDPRT
29.0 x 24.0 x 0.5 mm

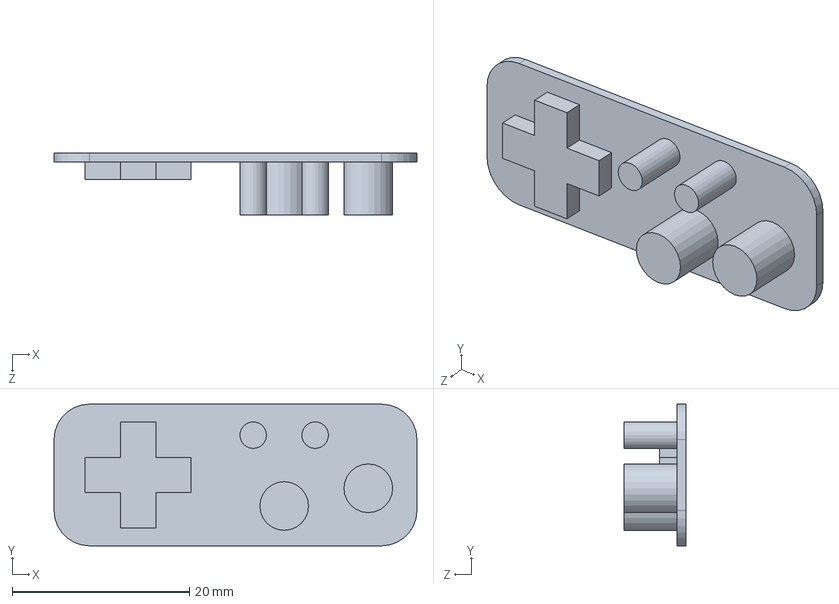
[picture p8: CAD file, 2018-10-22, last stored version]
hardware/3d_models/key_foam.SLDPRT
41.0 x 16.0 x 7.00 mm

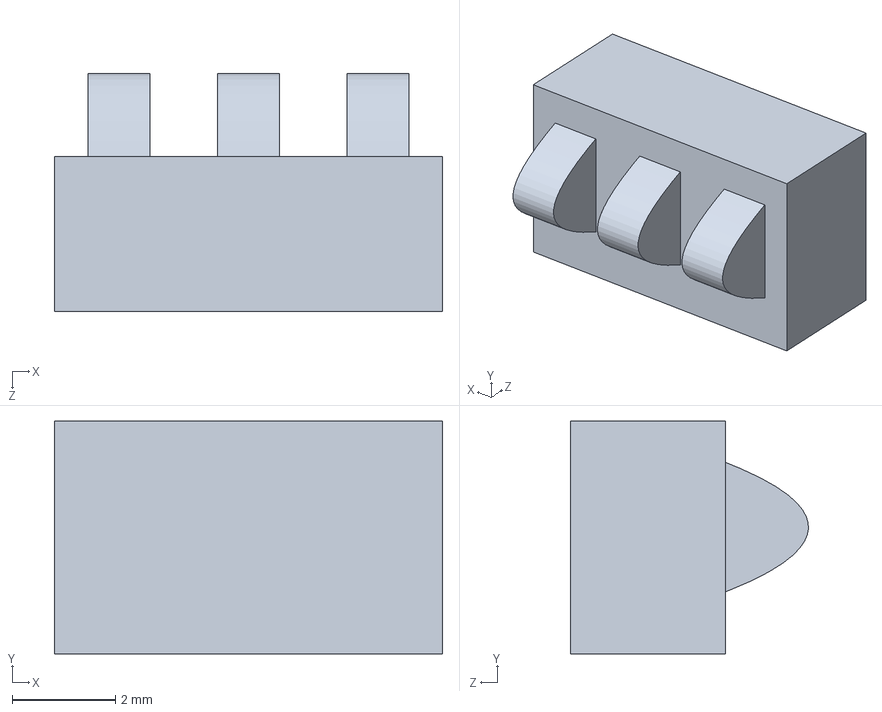
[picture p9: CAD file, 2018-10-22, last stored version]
hardware/3d_models/bc-15-3p.SLDPRT
7.50 x 4.50 x 4.60 mm

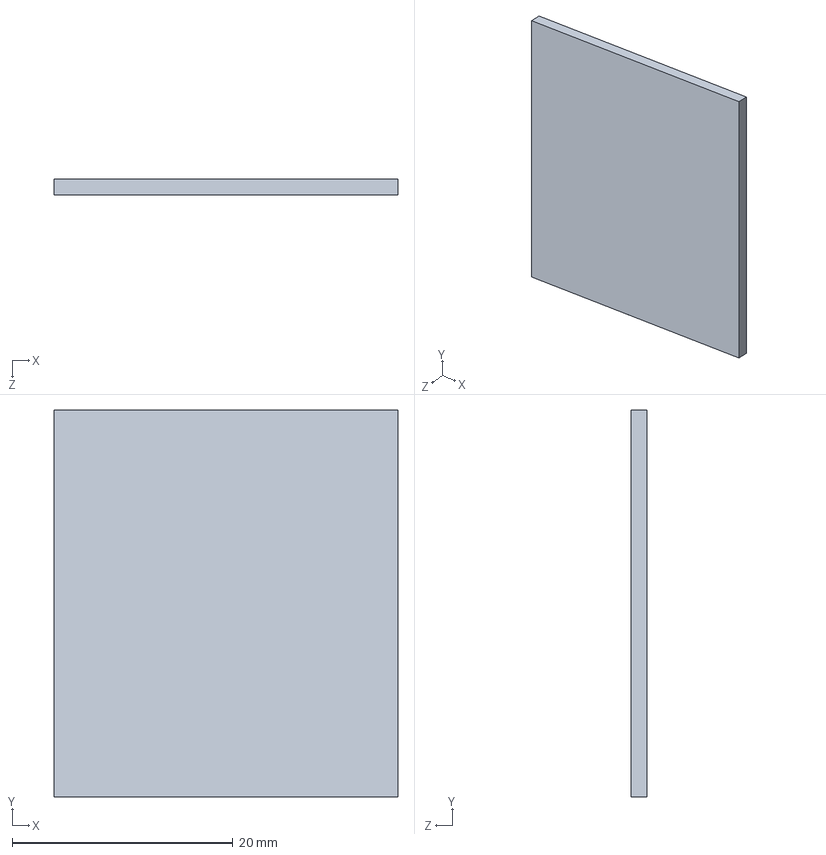
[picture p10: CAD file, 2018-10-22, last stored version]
hardware/3d_models/lcd.SLDPRT
31.2 x 35.1 x 1.42 mm

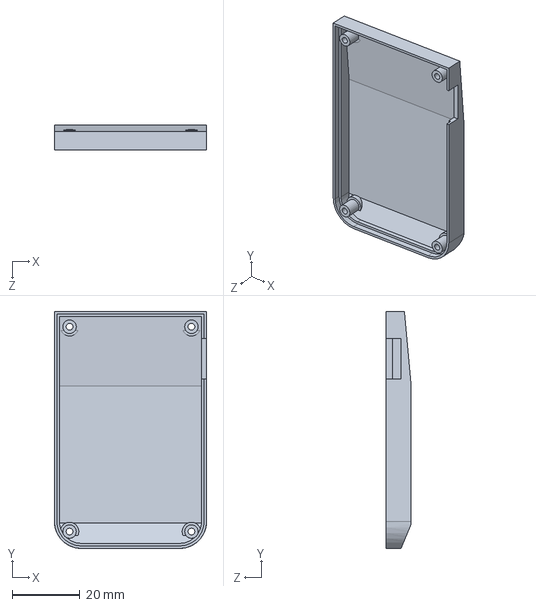
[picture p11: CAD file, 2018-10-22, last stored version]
hardware/3d_models/back_case.SLDPRT
45.0 x 70.0 x 7.50 mm

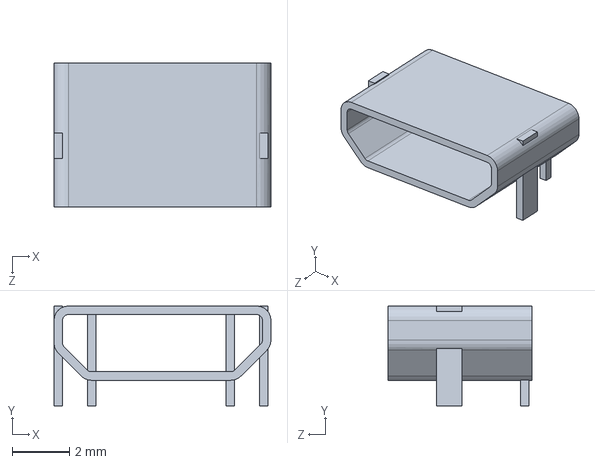
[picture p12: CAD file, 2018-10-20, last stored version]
hardware/3d_models/USBMicroF.SLDPRT
7.60 x 3.50 x 5.06 mm

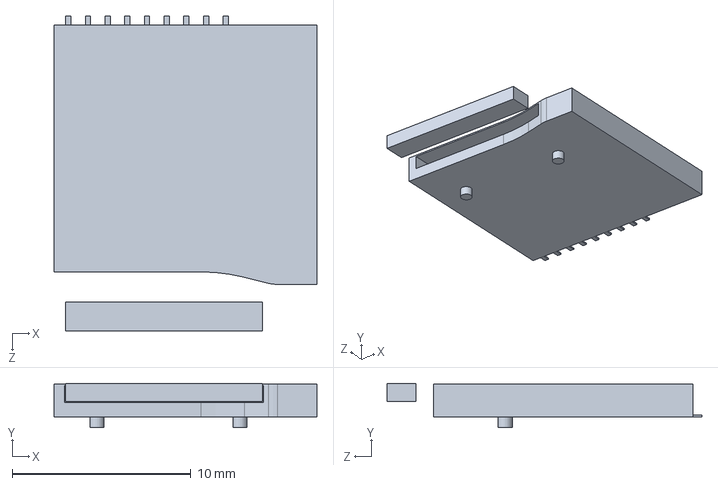
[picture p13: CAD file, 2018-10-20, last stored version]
hardware/3d_models/HY-TF1007B.SLDPRT
14.7 x 2.46 x 17.6 mm

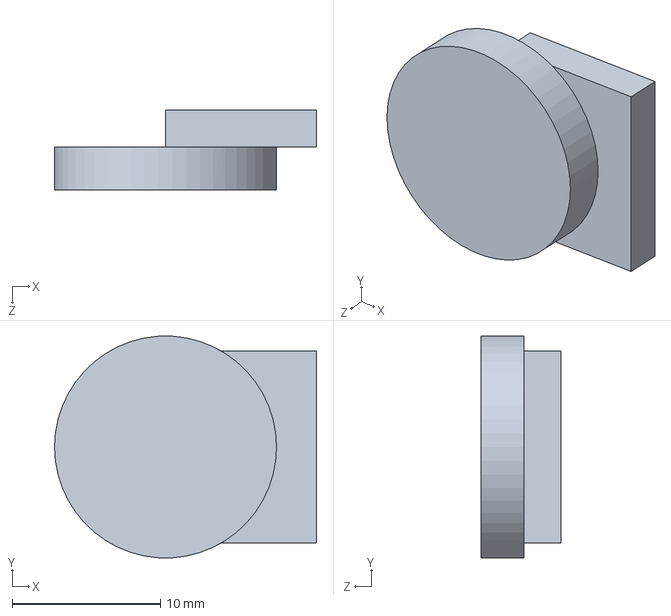
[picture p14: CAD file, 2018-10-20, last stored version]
hardware/3d_models/evqwk4.SLDPRT
17.7 x 15.0 x 5.40 mm

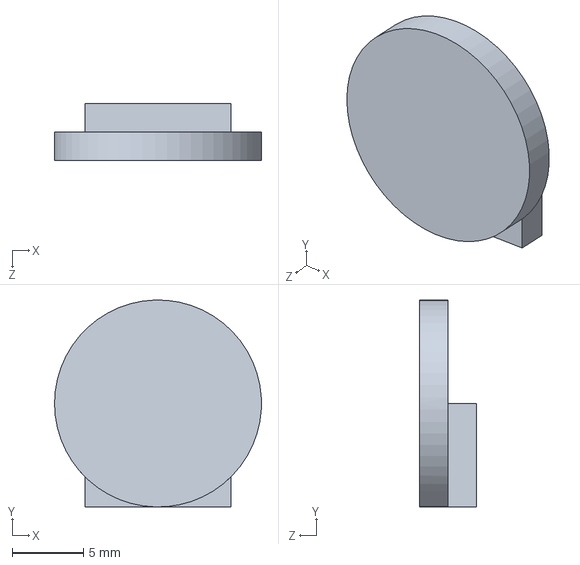
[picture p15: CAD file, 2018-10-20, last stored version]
hardware/3d_models/siq-02fvs3.SLDPRT
14.5 x 14.5 x 4.00 mm

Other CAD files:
hardware/3d_models/PJ-313D.SLDPRT
hardware/3d_models/bl_5c.SLDPRT
hardware/3d_models/bp_6m.SLDPRT
hardware/3d_models/dpad.SLDPRT
hardware/3d_models/HY-TF1007B.STL
hardware/3d_models/PJ-313D.STL
hardware/3d_models/USBMicroF.STL

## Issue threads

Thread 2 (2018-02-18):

PPU takes 176 clocks minimum to render a line rather than 172 on a real gameboy

zephray, 2018-02-18:
Not sure. Need further investigation. Leave it as is for now.

zephray, 2018-03-07:
The reason for this is that the fetch unit takes 6 clocks to fetch 8 pixels while the pixel fifo takes 8 clocks to output 8 pixels, so 2 wait states are needed by the fetch unit. However in current implementation, this 2 wait states would be inserted no matter if the fifo is empty or not. Also there is also 2 additional wait states before entering the H-blank.

Closed 2018-03-12.

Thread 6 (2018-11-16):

0402 Capacitors are too close to each other

zephray, 2018-11-16:
Can be potentially shorted after SMT.

Closed 2019-02-03.

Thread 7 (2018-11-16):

Pad of LQFP48 footprint is longer than necessary

zephray, 2018-11-16:

zephray, 2018-12-27:
Fixed in rev b

Closed 2018-12-27.

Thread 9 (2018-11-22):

Footprint of SMD LED is too wide

zephray, 2018-11-22:

Closed 2022-05-31.

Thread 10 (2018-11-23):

Request for more info about supported FPGAs

ndbroadbent, 2018-11-23:
Hello! This is such an awesome project. Nice work!

I saw in the README:

> Currently targeting on Xilinx ML505/XUPV5 and Terasic DE10-Lite. A dedicated handheld is in developement.

I found that the Xilinx ML505 board isn't being sold any more, but it uses a Virtex-5 LXT chip with 46K LEs. The [DE10-Lite](http://www.terasic.com.tw/cgi-bin/page/archive.pl?Language=english&No=1021) is really affordable, and I saw that it has a Altera MAX 10 with 50K LEs.

The reason I'm asking is because I'm updating my ["Best FPGA dev boards" post on /r/FPGA](https://www.reddit.com/r/FPGA/comments/9yutk8/best_100300_fpga_development_board_in_2018/), and I'm adding a link to VerilogBoy at the bottom. I'd like to know which FPGAs should have enough LUTs to run this.

Also I've just ordered a [numato Mimas A7](https://numato.com/product/mimas-a7-artix-7-fpga-development-board-with-ddr-sdram-and-gigabit-ethernet) with an Artix 7 FPGA that has 52K LEs. So I'm guessing VerilogBoy should be able to run on an Artix 7?

I also ordered a [iCE40-HX8K Breakout Board](http://www.latticesemi.com/en/Products/DevelopmentBoardsAndKits/iCE40HX8KBreakoutBoard.aspx), but this only has 7K LEs, so I'm assuming this won't be enough to run VerilogBoy. But it would be helpful to know how many LEs are actually required.

Thanks!

zephray, 2018-11-23:
Around 10K LEs are actually required to run the VerilogBoy, you might get some luck porting it to iCE40-HX8K board. Since everything in the refactor branch is WIP, I would suggest you switch to the master branch which contains a fully working ML505 port.

ndbroadbent, 2018-11-23:
Ok great, thank for your help! I will use the master branch for now. I look forward to getting my FPGA dev board and trying it out!

Closed 2018-11-23.

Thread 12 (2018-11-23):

Clock oscillator has pin 1 and 3 swapped

zephray, 2018-11-23:

Closed 2018-12-09.

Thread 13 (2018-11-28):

Pin 1 mark is missing for 3225 crystal footprint

zephray, 2018-11-28:

zephray, 2018-12-27:
Fixed in rev b

Closed 2018-12-27.

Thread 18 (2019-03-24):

Linux and MMU

letarg0, 2019-03-24:
In my opinion ARM (or whatewer else) procesor must have Memory unit for normal system like Linux. Linux can work on AT286 x86 but is not stable similar other project https://hackaday.com/2015/05/21/unix-on-your-breadboard/ etc.
MMU is very safety.

Second trouble is network. Today Lora, Wifi is very important. Think about this.

zephray, 2019-03-24:
Wait... But I don’t have Linux anywhere in the project, and that small ARM micro controller is subject to be removed. Networking can be a great add on, but only if it is possible to do so. Currently the size is the main limitation.

letarg0, 2019-03-24:
Every system need **MMU**.
Linux is for network, and meybe a second devices/core etc. MMU is for any system. Not only Linux.

MMU is important for any processor ;-) this is protect mode for separate programs. Look at psp, ps3 or other. One core is for system (prev. 2 cores) and other for game.

I like https://www.clockworkpi.com/ because i can easy write program. but...
meybe Your processor will be only coprocesor? Look at dingoo (small homebrew game console) or pandora. Simple mruby or embeded python can using MMU.

zephray, 2019-03-24:
I still do not understand your argument. There is absolutely no operating system running on it. The processor only handles power management and you can **not** run any user program on the processor.
I think you misunderstand the project.
For the VerilogBoy Handheld, this is an FPGA based handheld console, the main component here is the FPGA rather than a processor. The microcontroller is added merely for handling hardware specific configurations like codec or power management, also firmware upgrade for the FPGA. It is not designed to be user programmable, and is likely to be removed in the future in favor of doing everything inside the FPGA.
For the VerilogBoy Core, this is a re-creation of a GameBoy(R) compatible machine. The GameBoy does NOT have an MMU, so I don't see the point of adding an MMU to it since absolutely no software or game designed for GameBoy would utilize the MMU.
I understand the function of the MMU, and I know why I do not need an MMU. The Game runs in a separate processor inside the FPGA. It is a completely different processor with completely isolated memory space. There is no way they can interfere with each other by writing the memory.

zephray, 2019-03-25:
Thanks for opening up the issue. If I have answered your question, please close the issue. MMU is a necessity for multi-threaded operating system or any other case where memory sharing is required. But for this project, adding an MMU to an 80s 8-bit GameBoy architecture doesn't make much sense here. I will consider adding an MMU if other 32-bit soft processor is supported in the future.

Closed 2019-05-09.

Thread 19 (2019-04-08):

Documentation needed on installing dependencies

ggsubs, 2019-04-08:
INSTALL.md:

Getting the dependencies to build the firmware (arm-none-eabi-gcc, arm-none-eabi-newlib) and not documented. Listing the version tested with, and the source would be great.

Not clear which Picorv32 toolchain is needed from https://github.com/cliffordwolf/picorv32

zephray, 2019-04-08:
Currently pano-g1 target is not fully working. INSTALL.md is going to be replaced by building instructions located in target folders. I have been working on new documents but that would take some time. I am also going back and forth between different PicoRV32 toolchains, balancing code size and core size. Currently RV32IC, but might change in the future.

ggsubs, 2019-04-08:
Great, thanks, will wait. One particular concern the ISE 14.7 Linux VM comes with the aging Oracle EL6 version, and when it's upgraded even within EL6 it breaks the iMPACT USB drivers. At the same time gcc 4.7 required by the rv32 newlib installers.

zephray, 2019-04-08:
Yes, that's true. I am using Ubuntu 18.04 LTS + ISE 14.7 WebPACK. There are tutorials online about how to do this, and I managed to get it half working: The iMPACT USB driver only works when I login as root, ```sudo``` or ```su``` doesn't help. And the iMPACT sometimes refuse to reload the bitstream unless I restart the iMPACT. Probably the best setup would still be Windows 7 + ISE 14.7 WebPACK + Any modern Linux VM.
(Note: The ISE 14.7 for Windows 10 (bundled with Linux VM) doesn't support Spartan-3 on Pano Logic G1s so it could not be used.)

tomverbeure, 2019-04-08:
> Not clear which Picorv32 toolchain is needed from https://github.com/cliffordwolf/picorv32

FWIW: I just compile all versions. It only takes ~180MB per version.

Tom

ggsubs, 2019-04-13:
Succeeded building the fw on Ubuntu 16.04. Only when building the version separately, on by one:
make -j$(nproc) build-riscv32i-tools
make -j$(nproc) build-riscv32ic-tools
make -j$(nproc) build-riscv32im-tools
make -j$(nproc) build-riscv32imc-tools
Also great instructions on the serial cable: https://github.com/casper-astro/mlib_devel/wiki/How-to-install-Xilinx-ISE

zephray, 2019-04-14:
Good to hear you have got it to compile.
I tried that instruction, it didn't work for me under 18.04. I also tried another instruction for 18.04, with few changes, didn't work under regular user either.
I think it has something to do with usb device permissions, during to process of installing the driver in the instruction, it does add the vid/pid pair of Xilinx Platform Cable into a whitelist. I am using a Digilent HS cable, which is, probably not even supported by that driver. I am just glad the Digilent driver comes with ISE 14.7 still works under root privilege.

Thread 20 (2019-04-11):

Halt on USB

jroever, 2019-04-11:
Tried your latest panog1 to play with usb - got some life after removing old MIF includes in pick ROM and RAM modules - but running into HALT on USB. Was wondering if a) you have similar issues and b) could this be related to ISP1760 bug (found mention of workaround in SAF1760 documentation chapter 17.3.)

zephray, 2019-04-11:
I am not sure what exact situation you are in (like Halt on what device, when does it halt, etc.) But I can confirm I am having the similar issues in some cases:

- It should always be able to enumerate the ISP1760 internal hub (reports itself as ISP1520)
- It should always be able to enumerate the on-board SMSC 2513 USB Hub (this hub is added in RevC of PanoG1. On RevB devices it should not be there).
- It should always be able to enumerate devices connected to the Pano G1 RevC externally (whatever type it is, it should be able to get the descriptor, like VID PID, sorts of stuff).
- The USB HID driver should be able to communicate with the Nintendo Switch NGC-style controller fine. Occasionally timeout on setup. (Reason unknown, not critical, will auto retry, and retry would succeed.)
- The USB HID driver should be able to detect the DualShock4 controller, but fail to transmit any data through data EP. (results in HALT everytime)
- THe USB Mass Storage driver, should be able to communicate with BBB based devices (anything other than a floppy drive), but with limited compatibility. Some devices would always respond NAK (But I havn't seen HALT yet)
- The USB Mass Storage driver, when communicate with CBI based devices (floppy drives), it would fail to get an interrupt due to the limited interrupt transfer support, and eventually results in a HALT. (Will work on this soon.)

According to the datasheet,
> When low-speed or full-speed devices are connected through a high-speed hub, the problem will not occur
On PanoG1 RevC, there is an on-board HS hub (SMSC 2513), means external devices would be always connected through the HS hub. But If your device is a RevB, I would say, probably.

jroever, 2019-04-11:
Thanks for the quick and detailed response! Yes, I have a rev C and had forgotten about the external HUB (... but that's probably why that hub got added in Rev C - mystery solved :)
I was indeed trying with PS4 controller ... so if the halt is expected then I can start focusing on getting mouse HID to work instead (want ultra low latency trackball) - planning to do the INT/IRQ processing in HW and only do the device enumeration on pico - should be interesting hybrid. Thanks for all the solid pre-work to get USB alive!

zephray, 2019-04-12:
Yes, the PS4 controller is, fairly complicated. If you own a second gen PS4 controller as I did, it is capable of transmitting audio through the USB. The controller interface is, I remember the third or forth interface provided by the controller. I have to admit I havn't done any debugging about the PS4 controller situation... Will try to look into it.
Software and hardware hybrid sounds pretty interesting! By the way, in the ISP/SAF1760, I see for the interrupt transfer, there are few data bytes slots in the PTD. I am not sure what it is used for, and I am currently not using them, but my guess would be, it could be possible to just get the data from there. Just some thoughts.
Good luck, would like to hear more updates.

jroever, 2019-04-12:
... not sure if it makes any difference - but I just notice that
isp1760.c line 182:   isp_write_dword(ISP_PORT_1_CONTROL, 0x00800018);
seems to be setting reserved bits 2 & 1 not as per spec - should probably be 0x0080001e

jroever, 2019-04-12:
argh - never mind - I am such a sequential reader ;) just saw the footnote ...

zephray, 2019-04-13:
I did few modifications to optimize the RAM usage, now RAM size for PicoRV32 is reduced to 8KB (Not sure if 4KB is achievable or not). Tried my DualShock 4 again, and it mysteriously started working. Not sure why though.

jroever, 2019-04-16:
Interesting - I did find a few isp1760 settings that did not set the reserved bits as suggested - but it did not seem to change USB functionality.
I can now do a get_report on the control endpoint for a logitech mouse - but the same does not work for my kensington trackball or my Blue Pill USB mouse (which will be my centepede trackball controller)  ... they don't seem to support getting reports other than on the IRQ endpoint - which I have not working yet. Do you have keyboard and gamepads working with IRQ or via polling on the control port?
ISP1760 documentation is horrid - it talks about periodic transaction support and frame list registers - but once you dig down the USBCMD registers to enable some of this functionality aren't even present (or at least not documented) - sigh! Would be good to know how far you got with this ...

zephray, 2019-04-16:
Well, I only know the case for gamepads, the HID report should be sent through the interrupt endpoint, rather than the control endpoint.

So, what I have implemented here is... Polling on the interrupt endpoint.

Basically in my gamepad HID class driver, it will register a periodic interrupt transfer to the device driver:
https://github.com/zephray/VerilogBoy/blob/3b1de6af93990f8c6b7b30b9fa3d141c6fbc8e42/target/panog1/fw/firmware/usb_gamepad.c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

Then this periodic transfer is saved in the drivers periodic transfer list. But rather than using hardware IRQ or whatever periodic transfer function that ISP1760 is supported, I am just doing polling. The main function is supposed to call the polling function periodically:
https://github.com/zephray/VerilogBoy/blob/3b1de6af93990f8c6b7b30b9fa3d141c6fbc8e42/target/panog1/fw/firmware/isp1760.c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

This function would go through all the registered transfers, start an interrupt transfer, and wait till it finishes, read the payload back, and call the registered callback (from HID class driver).

Note this is not how things normally should be done. One should probably not wait on the interrupt transfer to be done, and it should probably not relying on my main function to call the driver to go and get the report. But basically I am just confused with ISP1760's documentation and implemented whatever I guessed should work.

Now all these are working, being able to get the data from interrupt endpoint, so it's usable, but probably not ideal.

zephray, 2019-04-16:
By the way, I used to try implement an interrupt based Interrupt Endpoint transfer:

1. Start an interrupt transfer but not wait for the finish.
2. When it finishes (either success or fail) an interrupt should be generated.
3. If it was success, read the payload out and call the HID class driver callback to parse the report.
4. Whatever the result was, start an new interrupt transfer and go to step 2.

The issue is, I don't always get the interrupt. Namely, when it stalls. Then if I don't get the interrupt, there will be no retry, and there will be no data, the loop just stuck on the step 2. This is probably related to my interrupt register configuration. In practice, the loop can run for around 5-15s before it stucks at step 2.

Again, I am not sure if this is how things should be done.

jroever, 2019-04-16:
Thanks, that helped a lot. Now I don't have to waste time trying to go down the road you already took ... I think I will try and see if I can use the SOF interrupt instead ... if I can get that going then we can have a kick off method that is synced with the USB timing but does not rely on success of prior transactions
BTW: in your G1 flash instructions - using firmware.elf instead of .bin works fine for me ... are you doing something special to alter the .bin?
PS:   Two questions
https://github.com/zephray/VerilogBoy/blob/3b1de6af93990f8c6b7b30b9fa3d141c6fbc8e42/target/panog1/fw/firmware/isp1760.c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

I have not done anything with HS devices, but shouldn't micro_frame for HS be zero?
Why are you setting micro_scs to FE not FF as per ISP1760?

zephray, 2019-04-16:
Hi.
No, I am not altering the .bin... For me, using .elf will generate the correct .mcs and works just fine, but the bar graph shown in the iMPACT are showing the raw .elf file size rather than the data size. I just feel like it is confusing so I recommend use .bin.
For the micro_frame and micro_scs... I just wrote it to be FF at first to set it to maximum value possible, for no specific reason. Setting micro_scs to FE is likely a bug, I was thinking something like the DONEMAP when I wrote these, but apparently it's not.
I have to say, in this driver, many values are basically arbitrarily chosen when I was writing the driver. Just feel free to ask and point out if it doesn't make much sense. Pull Requests would be very appreciated.

jroever, 2019-04-16:
Digging a bit deeper - I could not find where complete split transfers are done in isp1760.c - I only see the start splits for FS/LS endpoints ...
https://github.com/zephray/VerilogBoy/blob/3b1de6af93990f8c6b7b30b9fa3d141c6fbc8e42/target/panog1/fw/firmware/isp1760.c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

My code is currently a completely mutilated verilogboy clone while I am experimenting ... will do a pull request once I clean things back up :)

jroever, 2019-04-16:
Ok, I think I see it now - sneaky :) HW updates the SC bit ...

jroever, 2019-04-17:
I noticed that in firmware.asm the irq routine starts at e000_0008 but PROGADDR_IRQ for picorv is e000_0010 - was that intended?

zephray, 2019-04-17:
No... It’s a bug, apparently when I moved from RV32I to RV32IC, the address changed. I will fix it.

ggsubs, 2019-05-28:
I had issues getting a Midi keyboard up and running. The issue was about mismatching transfer lengths - a 0x4000 bit was coming on some devices. Masking it in isp1760.c solved it:

```    // If current direction is input, read payload back
    if (direction == DIRECTION_IN) {
        if (result == ISP_SUCCESS) {
            actual_transfer_length = actual_transfer_length & 0x0FFF;

zephray, 2019-05-30:
> I had issues getting a Midi keyboard up and running. The issue was about mismatching transfer lengths - a 0x4000 bit was coming on some devices. Masking it in isp1760.c solved it:

Thanks for pointing out, applied the fix in the last commit.

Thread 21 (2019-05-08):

编译成功，但运行出现错误

EV71, 2019-05-08:
提示
%Error: bootrom.mif:0: $readmem file not found
Aborting...
Aborted (core dumped)

zephray, 2019-05-09:
没有汇编启动ROM，请cd至roms运行make，README已更新

EV71, 2019-05-09:
> 没有汇编启动ROM，请cd至roms运行make，README已更新

其实在发帖之后成功编译了bootrom，貌似可以启动了。
但只能运行32K的ROM吗？试了好几ROM，32K都可以出来启动画面，非32K全部不行。

zephray, 2019-05-09:
请看源代码，仿真器中没有实现MBC仿真（因为MBC并非GameBoy一部分），故无法支持大于32K的ROM。之后为了调试需要可能会加入

Sent from my iPhone

On May 9, 2019, at 1:01 AM, EV71 <notifications@github.com<mailto:notifications@github.com>> wrote:

没有汇编启动ROM，请cd至roms运行make，README已更新

其实在发帖之后成功编译了bootrom，貌似可以启动了。
但只能运行32K的ROM吗？试了好几ROM，32K都可以出来启动画面，非32K全部不行。

—
You are receiving this because you commented.
Reply to this email directly, view it on GitHub<https://github.com/zephray/VerilogBoy/issues/21#issuecomment-490744169>, or mute the thread<https://github.com/notifications/unsubscribe-auth/ABG5QRIITL3Q5DRPYH2MDUDPUOVZBANCNFSM4HLVH4GA>.

EV71, 2019-05-09:
> 请看源代码，仿真器中没有实现MBC仿真（因为MBC并非GameBoy一部分），故无法支持大于32K的ROM。之后为了调试需要可能会加入
> […](#)
> Sent from my iPhone On May 9, 2019, at 1:01 AM, EV71 <notifications@github.com<mailto:notifications@github.com>> wrote: 没有汇编启动ROM，请cd至roms运行make，README已更新 其实在发帖之后成功编译了bootrom，貌似可以启动了。 但只能运行32K的ROM吗？试了好几ROM，32K都可以出来启动画面，非32K全部不行。 — You are receiving this because you commented. Reply to this email directly, view it on GitHub<[#21 (comment)](https://github.com/zephray/VerilogBoy/issues/21#issuecomment-490744169)>, or mute the thread<https://github.com/notifications/unsubscribe-auth/ABG5QRIITL3Q5DRPYH2MDUDPUOVZBANCNFSM4HLVH4GA>.

完全明白，谢谢你的回答。

Closed 2019-05-13.

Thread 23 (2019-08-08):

can't build Pano G1 from current code

skiphansen, 2019-08-08:
I built Verilogboy successfully prior to the move to XIP.  Now the build fails with "ERROR:Xst:1918 - "../../../rtl/brom.v" line 30: Unable to find file "bootrom.mif"."

skiphansen, 2019-08-09:
Reading the documentation helps!  I hadn't built the bootrom (duh)!  If you follow the readme.md it builds fine.

Closed 2019-08-09.

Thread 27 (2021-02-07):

Use actual gameboy carts?

Qiangong2, 2021-02-07:
Is it possible to use actual gameboy cartridges with this?

zephray, 2021-02-08:
Yes it's supported. The internally simulated cartridge use the same signal and pinout as the real cartridge, so you can just connect a real cartridge there. I was planning to make a demo hardware with real cartridge, but didn't quite have time to do.

blazer82, 2021-11-10:
Jumping in here.. I actually built hardware with a real cartridge slot and got Tetris working. I needed to invert some of the signals (RD, WR, CS, RST) because they're active low and I think you got them active high in your HDL. Not a problem, though!

Tetris is fairly simple and doesn't use anything else besides RD and the address bus and data bus.
I could not get Super Mario Land to work, however. All I get is scrambled output on the screen. I suppose it has something to do with it using MBC1. Did any of you get this working properly and maybe has any idea what I'm doing wrong?

Anyway, I'll try to debug this and will report any findings here.

zephray, 2021-11-10:
@blazer82  Hi, great that you got it working! The active high was more or less a coding style issue, I wanted to keep all internal signals active high, and invert them as needed in the top-level when interfacing with hardware. But as with all coding style issues, that's just personal preference.

Regarding the MBC1 issue, I would assume you've stripped out the mbc5.v implementation and wired the bus directly to the cart. One issue I can think of is that the current vb implementation doesn't generate CS signal. Cartridges with builtin RAM could rely on this signal to function correctly. Try implement the CS logic and see if it make any difference. (Ideally it should also check the address range to see if it should be asserted, but as a quick starting point, assign cs = rd | wr; (or assign cs_n = rd_n & wr_n;) should do the trick.

blazer82, 2021-11-10:
@zephray Thanks for the quick response! You're right, CS isn't being driven right now yet it is wired up inside the cartridge, so it's probably used for something. I'll have a look at that and try your proposed solution and then report back.

Also, I agree regarding the active signals: In code I think active high makes more sense yet electrically I prefer active low. I can totally see why you did this and it's no hassle to just invert it.

blazer82, 2021-11-11:
@zephray having `cs = rd & wr` which would make it active low whenever rd or wr is active low kind of makes sense yet it did not work. Got the same garbage on the screen.

I then tried `cs = ~(gb_a >= 16'hA000 && gb_a <= 16'hFDFF)` since I read somewhere that it's supposed to be active for addresses in that range only. This change got me stuck in a bootrom loop. At least, that's something new 😅

zephray, 2021-11-11:
Just checked that Super Mario Land works in the simulator so I guess this shouldn't be a compatibility issue with the core itself... (./sim/verilator/vb_sim SuperMarioLand.gb --nostop --mbc). I noticed that the cartridge doesn't have any kind of RAM builtin, so the cartridge shouldn't do anything with address higher than A000.

blazer82, 2021-11-11:
Sounds promising, thanks for testing that out! I suppose I must have something wrong with the wiring in HDL.

I was also thinking that Super Mario Land isn’t supposed to have RAM and you’re right the switchable ROM should all be below 0x8000.

I’m gonna investigate further 😊

blazer82, 2021-11-12:
I fixed it! Turns out CS isn't needed and I have it pulled up all the time.

The issue was me still being a total noob in terms of FPGA programming and not knowing how to properly wire up the date bus for read and write operations. After some googling I figured it out and works like a charm.

As the issue was never with VerilogBoy and I now confirmed that it indeed works with real cartridges, I suggest closing this issue 😊

Closed 2021-12-13.

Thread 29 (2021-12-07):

Super Mario Land hangs when entering bonus game

blazer82, 2021-12-07:
As you know, I use your VerilogBoy with real cartridges instead of ROM images and I ran into an issue with _Super Mario Land_ that I'm not sure where it's originating.

**_Issue_**

When _Super Mario Land_ is supposed to enter the bonus game (triggered by exiting through the upper door in level 1 and 2 or by finishing level 3), the execution of the game hangs.

So far I have determined that:

- The execution is caught up in a loop between PC `0x97` and `0x9C` which is basically the following loop:

```
LDH A, [$FF41]
ADD $03
JR NZ, $FA
```

- The loop waits for an HSYNC to occur that just won't happen.
- The _stat register_ at `0xFF41` keeps a constant value of `0x41` and the PPU state stays on `s_IDLE` forever.

**_Steps to reproduce_**

Exit level 1 or 2 through the upper door or finish level 3.

**_Further considerations_**

I'm not sure yet whether this is a general issue with VerilogBoy or whether this only arises when using real cartridges. It may be helpful to know if you can reproduce this behavior at all.

I'll keep looking for the root cause but any suggestions on what might be the issue are very welcome 😊

zephray, 2021-12-07:
Hi, thanks for the feedback. My initial guess would be that's a bug in the PPU. While the CPU/ Timer/ PSG are well tested, the PPU isn't. But the fact that the PPU stays in IDLE tends to suggest that the PPU is turned off for some reason. Just by looking at the PPU logic, it would exit IDLE when vblank comes and the LCD is enabled. HV timing counter is always running regardless of the other states or registers, so the Vblank would always come. That means the LCD is disabled. So the next step would be:
1. Verify if LCD is really disabled or not.
2. If it is disabled, should it be disabled?
3. If it should be disabled, should STAT register indicate the LCD is in VBlank or not?

blazer82, 2021-12-07:
@zephray thanks for the very fast reply! 😊

>That means the LCD is disabled

From looking at the code, that's my current best guess, too. I'll try to verify that and if successful try to answer the to follow-up questions you mentioned.

Very helpful, thank you! I'll update this thread with any findings.

blazer82, 2021-12-08:
>1. Verify if LCD is really disabled or not.

I confirmed that the _LCDC_ goes to `0x00`, so the LCD really is disabled at that point.

blazer82, 2021-12-08:
I found [this reddit post](https://www.reddit.com/r/Gameboy/comments/a1c8h0/comment/eap4f8c/?context=3) that seems to suggest that

>the LCD enters Mode 0

when disabled which would provide an answer to

>3. If it should be disabled, should STAT register indicate the LCD is in VBlank or not?

while most likely also resolving the issue.

I'll be back with updates...

blazer82, 2021-12-08:
Fixed it! I'll create a pull request.

Closed 2021-12-13.

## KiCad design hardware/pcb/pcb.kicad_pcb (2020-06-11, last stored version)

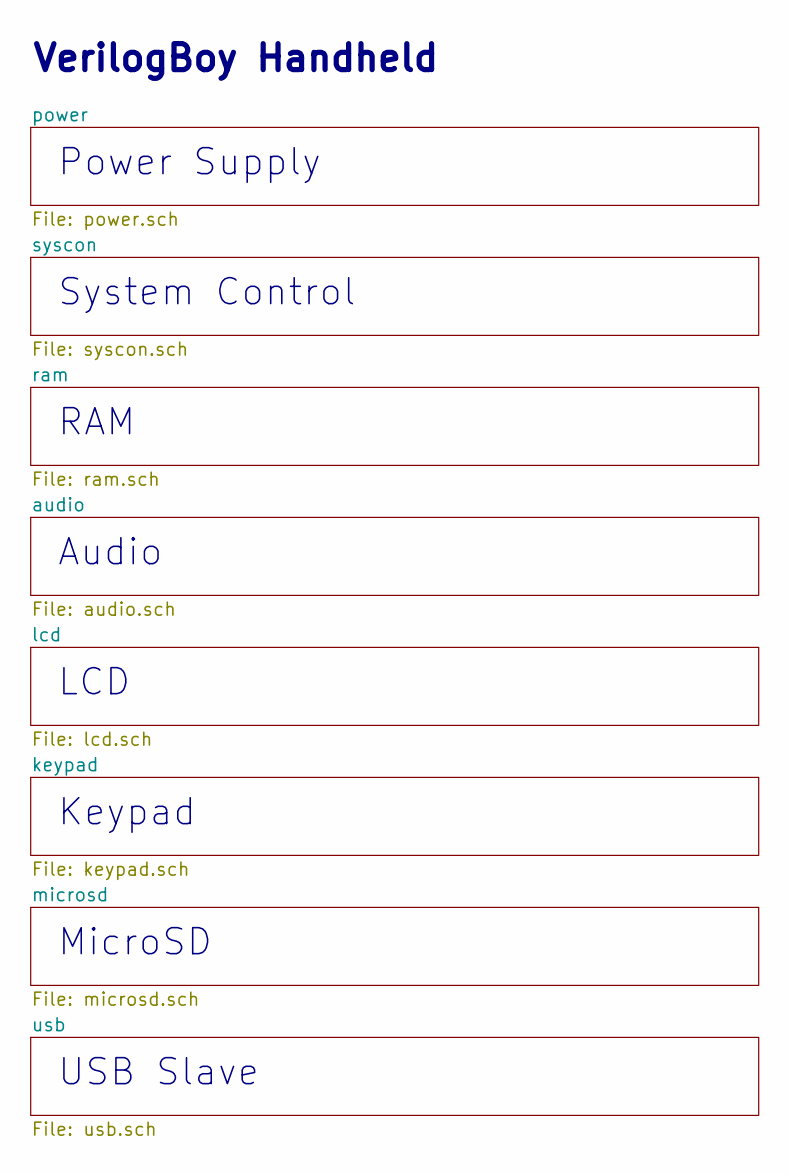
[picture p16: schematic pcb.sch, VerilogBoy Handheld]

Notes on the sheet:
VerilogBoy Handheld
Power Supply
System Control
RAM
Audio
LCD
Keypad
MicroSD
USB Slave

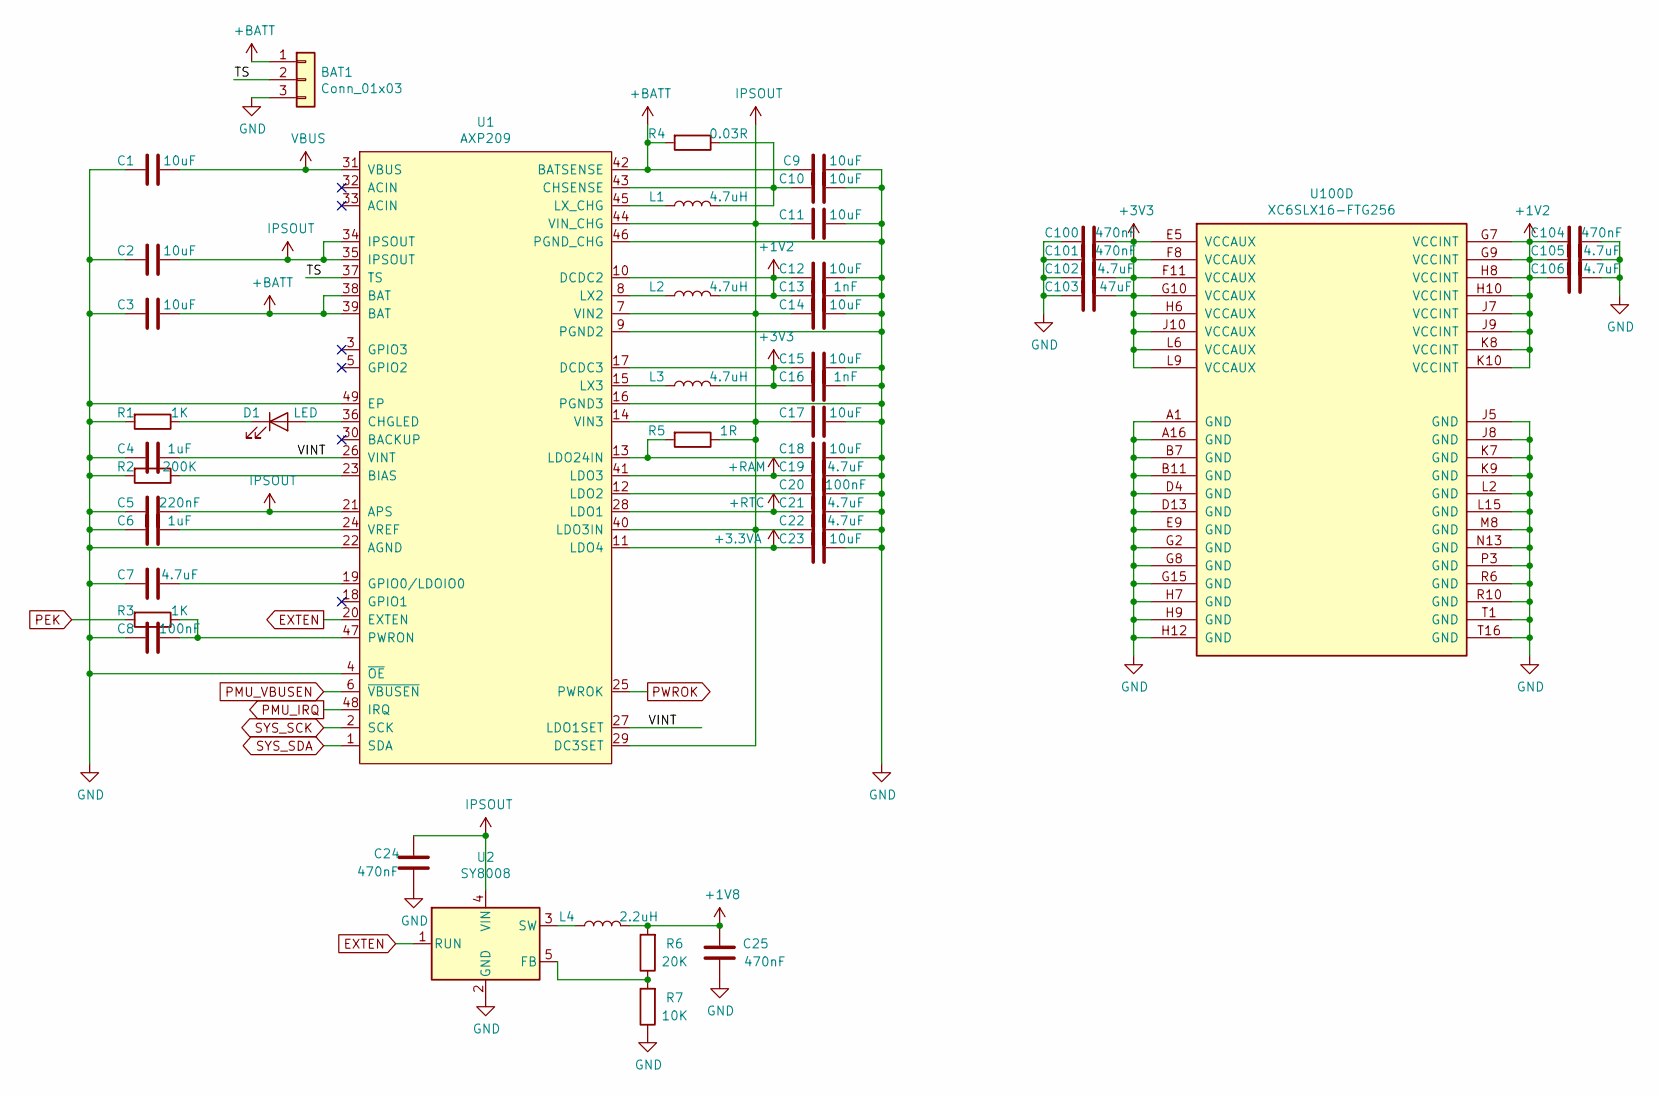
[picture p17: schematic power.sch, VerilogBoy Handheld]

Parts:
BAT1: Conn_01x03; BC-15-3P
C1, C2, C3, C9, C10, C11, C12, C14, C15, C17, C18, C23: 10uF; C_0603_1608Metric
C4, C6: 1uF; C_0402_1005Metric
C5: 220nF; C_0402_1005Metric
C7, C19, C21, C22, C102, C105, C106: 4.7uF; C_0603_1608Metric
C8, C20: 100nF; C_0402_1005Metric
C13, C16: 1nF; C_0402_1005Metric
C24, C25, C100, C101, C104: 470nF; C_0402_1005Metric
C103: 47uF; C_0805_2012Metric
D1: LED; D_0603_1608Metric
L1, L2, L3: 4.7uH; L_Vishay_IHLP-1212
L4: 2.2uH; L_Vishay_IHLP-1212
R1, R3: 1K; R_0402_1005Metric
R2: 200K; R_0402_1005Metric
R4: 0.03R; R_0805_2012Metric
R5: 1R; R_0603_1608Metric
R6: 20K; R_0402_1005Metric
R7: 10K; R_0402_1005Metric
U1: AXP209; QFN-48-1EP_6x6mm_P0.4mm_EP4.2x4.2mm_ThermalVias
U2: SY8008; TSOT-23-5
U100: XC6SLX16-FTG256; Xilinx_FTG256

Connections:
+1V2: C12.2, C13.2, C104.2, C105.2, C106.2, L2.2, U1.10 (DCDC2), U100.G7 (VCCINT), U100.G9 (VCCINT), U100.H8 (VCCINT), U100.H10 (VCCINT), U100.J7 (VCCINT), U100.J9 (VCCINT), U100.K8 (VCCINT), U100.K10 (VCCINT); also elsewhere on the board
+1V8: C25.2, L4.2, R6.2; also elsewhere on the board
+3.3VA: C23.2, U1.11 (LDO4); also elsewhere on the board
+3V3: C15.2, C16.2, C100.1, C101.1, C102.1, C103.1, L3.2, U1.17 (DCDC3), U100.E5 (VCCAUX), U100.F8 (VCCAUX), U100.F11 (VCCAUX), U100.G10 (VCCAUX), U100.H6 (VCCAUX), U100.J10 (VCCAUX), U100.L6 (VCCAUX), U100.L9 (VCCAUX); also elsewhere on the board
+BATT: BAT1.1, C3.1, C9.2, R4.2, U1.38 (BAT), U1.39 (BAT), U1.42 (BATSENSE)
+RAM: C19.2, U1.41 (LDO3); also elsewhere on the board
+RTC: C21.2, U1.28 (LDO1)
/power/TS: BAT1.2, U1.37 (TS)
/power/VINT: C4.1, U1.26 (VINT), U1.27 (LDO1SET)
EXTEN: U1.20 (EXTEN), U2.1 (RUN)
GND: BAT1.3, C1.2, C2.2, C3.2, C4.2, C5.2, C6.2, C7.2, C8.2, C9.1, C10.1, C11.1, C12.1, C13.1, C14.1, C15.1, C16.1, C17.1, C18.1, C19.1, C20.1, C21.1, C22.1, C23.1, C24.1, C25.1, C100.2, C101.2, C102.2, C103.2, C104.1, C105.1, C106.1, R1.2, R2.2, R7.1, U1.4 (~OE), U1.9 (PGND2), U1.16 (PGND3), U1.22 (AGND), U1.46 (PGND_CHG), U1.49 (EP), U2.2 (GND), U100.A1 (GND), U100.A16 (GND), U100.B7 (GND), U100.B11 (GND), U100.D4 (GND), U100.D13 (GND), U100.E9 (GND), U100.G2 (GND), U100.G8 (GND), U100.G15 (GND), U100.H7 (GND), U100.H9 (GND), U100.H12 (GND), U100.J5 (GND), U100.J8 (GND), U100.K7 (GND), U100.K9 (GND), U100.L2 (GND), U100.L15 (GND), U100.M8 (GND), U100.N13 (GND), U100.P3 (GND), U100.R6 (GND), U100.R10 (GND), U100.T1 (GND), U100.T16 (GND); also elsewhere on the board
IPSOUT: C2.1, C5.1, C11.2, C14.2, C17.2, C22.2, C24.2, R5.1, U1.7 (VIN2), U1.14 (VIN3), U1.21 (APS), U1.29 (DC3SET), U1.34 (IPSOUT), U1.35 (IPSOUT), U1.40 (LDO3IN), U1.44 (VIN_CHG), U2.4 (VIN)
unnamed: C6.1, U1.24 (VREF)
unnamed: C7.1, U1.19 (GPIO0/LDOIO0)
unnamed: C8.1, R3.1, U1.47 (PWRON)
unnamed: C10.2, L1.2, R4.1, U1.43 (CHSENSE)
unnamed: C18.2, R5.2, U1.13 (LDO24IN)
unnamed: C20.2, U1.12 (LDO2)
unnamed: D1.1 (K), R1.1
unnamed: D1.2 (A), U1.36 (CHGLED)
unnamed: L1.1, U1.45 (LX_CHG)
unnamed: L2.1, U1.8 (LX2)
unnamed: L3.1, U1.15 (LX3)
unnamed: L4.1, U2.3 (SW)
unnamed: R2.1, U1.23 (BIAS)
unnamed: R6.1, R7.2, U2.5 (FB)
PEK: R3.2; also elsewhere on the board
PMU_IRQ: U1.48 (IRQ); also elsewhere on the board
PMU_VBUSEN: U1.6 (~VBUSEN); also elsewhere on the board
PWROK: U1.25 (PWROK); also elsewhere on the board
SYS_SDA: U1.1 (SDA); also elsewhere on the board
VBUS: C1.1, U1.31 (VBUS); also elsewhere on the board

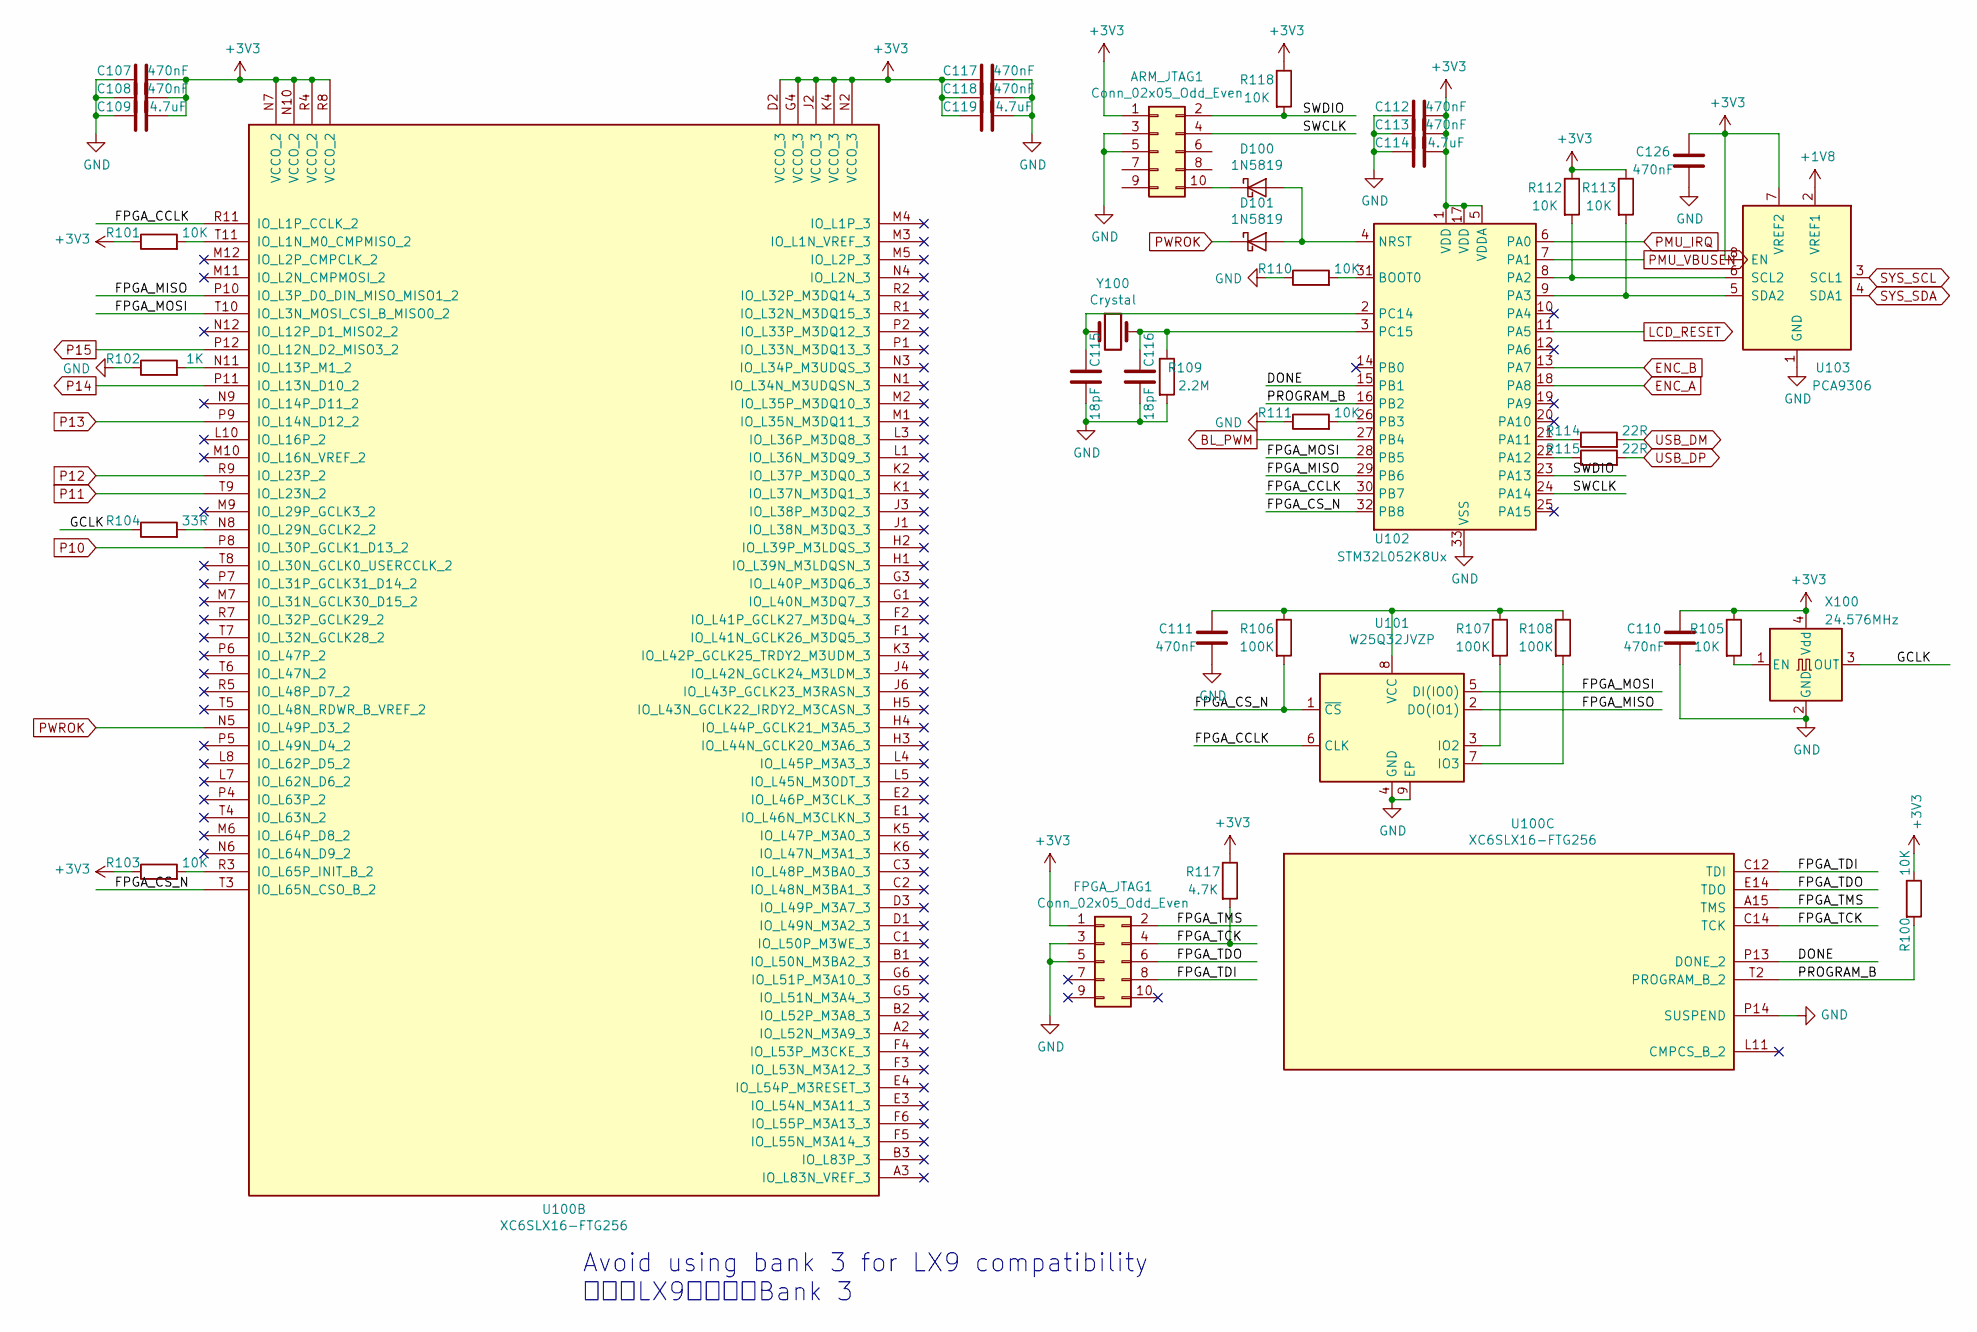
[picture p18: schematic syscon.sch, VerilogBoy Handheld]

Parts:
ARM_JTAG1: Conn_02x05_Odd_Even; PinHeader_2x05_P1.27mm_Vertical_SMD
C107, C108, C110, C111, C112, C113, C117, C118, C126: 470nF; C_0402_1005Metric
C109, C114, C119: 4.7uF; C_0603_1608Metric
C115, C116: 18pF; C_0402_1005Metric
D100, D101: 1N5819; D_SOD-123
FPGA_JTAG1: Conn_02x05_Odd_Even; PinHeader_2x05_P1.27mm_Vertical_SMD
R100, R101, R103, R105, R110, R111, R112, R113, R118: 10K; C_0402_1005Metric
R102: 1K; C_0402_1005Metric
R104: 33R; C_0402_1005Metric
R106, R107, R108: 100K; C_0402_1005Metric
R109: 2.2M; C_0402_1005Metric
R114, R115: 22R; C_0402_1005Metric
R117: 4.7K; C_0402_1005Metric
U100: XC6SLX16-FTG256; Xilinx_FTG256
U101: W25Q32JVZP; WSON-8-1EP_6x5mm_P1.27mm_EP3.4x4.3mm
U102: STM32L052K8Ux; QFN-32-1EP_5x5mm_P0.5mm_EP3.45x3.45mm
U103: PCA9306; VSSOP-8_2.3x2mm_P0.5mm
X100: 24.576MHz; Oscillator_SMD_Abracon_ASE-4Pin_3.2x2.5mm
Y100: Crystal; Crystal_SMD_TXC_9HT11-2Pin_2.0x1.2mm_HandSoldering

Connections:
+1V8: U103.2 (VREF1); also elsewhere on the board
+3V3: ARM_JTAG1.1, C107.1, C108.1, C109.1, C110.2, C112.1, C113.1, C114.1, C117.2, C118.2, C119.2, C126.2, FPGA_JTAG1.1, R100.1, R101.1, R103.1, R105.1, R112.1, R113.1, R117.1, R118.1, U100.D2 (VCCO_3), U100.G4 (VCCO_3), U100.J2 (VCCO_3), U100.K4 (VCCO_3), U100.N2 (VCCO_3), U100.N7 (VCCO_2), U100.N10 (VCCO_2), U100.R4 (VCCO_2), U100.R8 (VCCO_2), U102.1 (VDD), U102.5 (VDDA), U102.17 (VDD), U103.7 (VREF2), U103.8 (EN), X100.4 (Vdd); also elsewhere on the board
/syscon/DONE: U100.P13 (DONE_2), U102.15 (PB1)
/syscon/FPGA_CCLK: U100.R11 (IO_L1P_CCLK_2), U101.6 (CLK), U102.30 (PB7)
/syscon/FPGA_CS_N: R106.2, U100.T3 (IO_L65N_CSO_B_2), U101.1 (~CS), U102.32 (PB8)
/syscon/FPGA_MISO: U100.P10 (IO_L3P_D0_DIN_MISO_MISO1_2), U101.2 (DO(IO1)), U102.29 (PB6)
/syscon/FPGA_MOSI: U100.T10 (IO_L3N_MOSI_CSI_B_MISO0_2), U101.5 (DI(IO0)), U102.28 (PB5)
/syscon/FPGA_TCK: FPGA_JTAG1.4, R117.2, U100.C14 (TCK)
/syscon/FPGA_TDI: FPGA_JTAG1.8, U100.C12 (TDI)
/syscon/FPGA_TDO: FPGA_JTAG1.6, U100.E14 (TDO)
/syscon/FPGA_TMS: FPGA_JTAG1.2, U100.A15 (TMS)
/syscon/GCLK: R104.1, X100.3 (OUT)
/syscon/PROGRAM_B: R100.2, U100.T2 (PROGRAM_B_2), U102.16 (PB2)
/syscon/SWCLK: ARM_JTAG1.4, U102.24 (PA14)
/syscon/SWDIO: ARM_JTAG1.2, R118.2, U102.23 (PA13)
ENC_A: U102.18 (PA8); also elsewhere on the board
ENC_B: U102.13 (PA7); also elsewhere on the board
GND: ARM_JTAG1.3, ARM_JTAG1.5, C107.2, C108.2, C109.2, C110.1, C111.1, C112.2, C113.2, C114.2, C115.1, C116.1, C117.1, C118.1, C119.1, C126.1, FPGA_JTAG1.3, FPGA_JTAG1.5, R102.1, R109.2, R110.1, R111.1, U100.P14 (SUSPEND), U101.4 (GND), U101.9 (EP), U102.33 (VSS), U103.1 (GND), X100.2 (GND); also elsewhere on the board
LCD_RESET: U102.11 (PA5); also elsewhere on the board
unnamed: ARM_JTAG1.10, D100.1 (K)
unnamed: C111.2, R106.1, R107.1, R108.1, U101.8 (VCC)
unnamed: C115.2, U102.2 (PC14), Y100.1
unnamed: C116.2, R109.1, U102.3 (PC15), Y100.2
unnamed: D100.2 (A), D101.2 (A), U102.4 (NRST)
unnamed: R101.2, U100.T11 (IO_L1N_M0_CMPMISO_2)
unnamed: R102.2, U100.N11 (IO_L13P_M1_2)
unnamed: R103.2, U100.R3 (IO_L65P_INIT_B_2)
unnamed: R104.2, U100.N8 (IO_L29N_GCLK2_2)
unnamed: R105.2, X100.1 (EN)
unnamed: R107.2, U101.3 (IO2)
unnamed: R108.2, U101.7 (IO3)
unnamed: R110.2, U102.31 (BOOT0)
unnamed: R111.2, U102.26 (PB3)
unnamed: R112.2, U102.8 (PA2), U103.6 (SCL2)
unnamed: R113.2, U102.9 (PA3), U103.5 (SDA2)
unnamed: R114.1, U102.21 (PA11)
unnamed: R115.1, U102.22 (PA12)
P10: U100.P8 (IO_L30P_GCLK1_D13_2); also elsewhere on the board
P11: U100.T9 (IO_L23N_2); also elsewhere on the board
P12: U100.R9 (IO_L23P_2); also elsewhere on the board
P13: U100.P9 (IO_L14N_D12_2); also elsewhere on the board
P14: U100.P11 (IO_L13N_D10_2); also elsewhere on the board
P15: U100.P12 (IO_L12N_D2_MISO3_2); also elsewhere on the board
PMU_IRQ: U102.6 (PA0); also elsewhere on the board
PMU_VBUSEN: U102.7 (PA1); also elsewhere on the board
PWROK: D101.1 (K), U100.N5 (IO_L49P_D3_2); also elsewhere on the board
SYS_SCL: U103.3 (SCL1); also elsewhere on the board
SYS_SDA: U103.4 (SDA1); also elsewhere on the board
USB_DM: R114.2; also elsewhere on the board
USB_DP: R115.2; also elsewhere on the board

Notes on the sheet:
Avoid using bank 3 for LX9 compatibility 为兼容LX9避免使用Bank 3

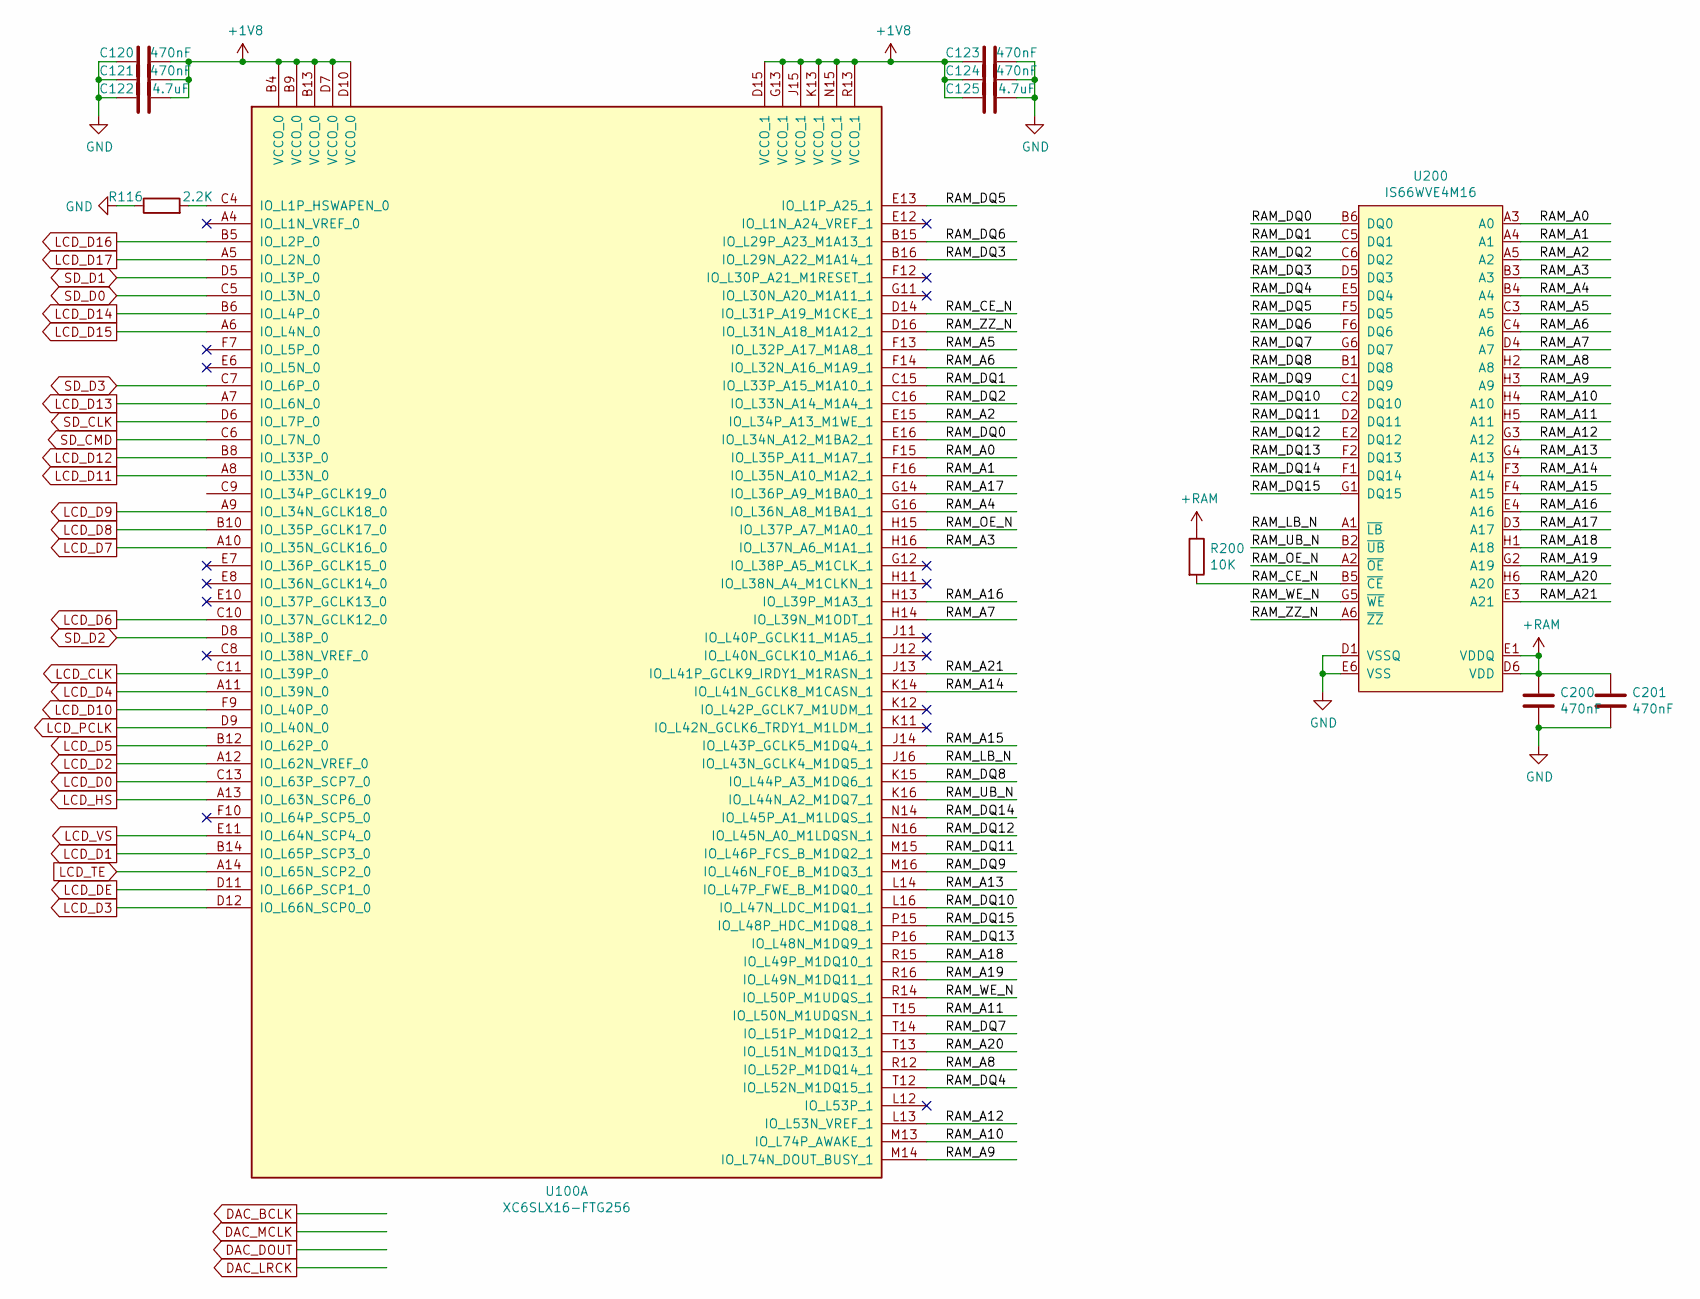
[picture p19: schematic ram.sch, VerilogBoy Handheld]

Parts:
C120, C121, C123, C124, C200, C201: 470nF; C_0402_1005Metric
C122, C125: 4.7uF; C_0603_1608Metric
R116: 2.2K; C_0402_1005Metric
R200: 10K; R_0402_1005Metric
U100: XC6SLX16-FTG256; Xilinx_FTG256
U200: IS66WVE4M16; BGA-48_6x8_6.0x8.0mm

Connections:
+1V8: C120.1, C121.1, C122.1, C123.2, C124.2, C125.2, U100.B4 (VCCO_0), U100.B9 (VCCO_0), U100.B13 (VCCO_0), U100.D7 (VCCO_0), U100.D10 (VCCO_0), U100.D15 (VCCO_1), U100.G13 (VCCO_1), U100.J15 (VCCO_1), U100.K13 (VCCO_1), U100.N15 (VCCO_1), U100.R13 (VCCO_1); also elsewhere on the board
+RAM: C200.1, C201.1, R200.1, U200.D6 (VDD), U200.E1 (VDDQ); also elsewhere on the board
/ram/RAM_A0: U100.F15 (IO_L35P_A11_M1A7_1), U200.A3 (A0)
/ram/RAM_A1: U100.F16 (IO_L35N_A10_M1A2_1), U200.A4 (A1)
/ram/RAM_A2: U100.E15 (IO_L34P_A13_M1WE_1), U200.A5 (A2)
/ram/RAM_A3: U100.H16 (IO_L37N_A6_M1A1_1), U200.B3 (A3)
/ram/RAM_A4: U100.G16 (IO_L36N_A8_M1BA1_1), U200.B4 (A4)
/ram/RAM_A5: U100.F13 (IO_L32P_A17_M1A8_1), U200.C3 (A5)
/ram/RAM_A6: U100.F14 (IO_L32N_A16_M1A9_1), U200.C4 (A6)
/ram/RAM_A7: U100.H14 (IO_L39N_M1ODT_1), U200.D4 (A7)
/ram/RAM_A8: U100.R12 (IO_L52P_M1DQ14_1), U200.H2 (A8)
/ram/RAM_A9: U100.M14 (IO_L74N_DOUT_BUSY_1), U200.H3 (A9)
/ram/RAM_A10: U100.M13 (IO_L74P_AWAKE_1), U200.H4 (A10)
/ram/RAM_A11: U100.T15 (IO_L50N_M1UDQSN_1), U200.H5 (A11)
/ram/RAM_A12: U100.L13 (IO_L53N_VREF_1), U200.G3 (A12)
/ram/RAM_A13: U100.L14 (IO_L47P_FWE_B_M1DQ0_1), U200.G4 (A13)
/ram/RAM_A14: U100.K14 (IO_L41N_GCLK8_M1CASN_1), U200.F3 (A14)
/ram/RAM_A15: U100.J14 (IO_L43P_GCLK5_M1DQ4_1), U200.F4 (A15)
/ram/RAM_A16: U100.H13 (IO_L39P_M1A3_1), U200.E4 (A16)
/ram/RAM_A17: U100.G14 (IO_L36P_A9_M1BA0_1), U200.D3 (A17)
/ram/RAM_A18: U100.R15 (IO_L49P_M1DQ10_1), U200.H1 (A18)
/ram/RAM_A19: U100.R16 (IO_L49N_M1DQ11_1), U200.G2 (A19)
/ram/RAM_A20: U100.T13 (IO_L51N_M1DQ13_1), U200.H6 (A20)
/ram/RAM_A21: U100.J13 (IO_L41P_GCLK9_IRDY1_M1RASN_1), U200.E3 (A21)
/ram/RAM_CE_N: R200.2, U100.D14 (IO_L31P_A19_M1CKE_1), U200.B5 (~CE)
/ram/RAM_DQ0: U100.E16 (IO_L34N_A12_M1BA2_1), U200.B6 (DQ0)
/ram/RAM_DQ1: U100.C15 (IO_L33P_A15_M1A10_1), U200.C5 (DQ1)
/ram/RAM_DQ2: U100.C16 (IO_L33N_A14_M1A4_1), U200.C6 (DQ2)
/ram/RAM_DQ3: U100.B16 (IO_L29N_A22_M1A14_1), U200.D5 (DQ3)
/ram/RAM_DQ4: U100.T12 (IO_L52N_M1DQ15_1), U200.E5 (DQ4)
/ram/RAM_DQ5: U100.E13 (IO_L1P_A25_1), U200.F5 (DQ5)
/ram/RAM_DQ6: U100.B15 (IO_L29P_A23_M1A13_1), U200.F6 (DQ6)
/ram/RAM_DQ7: U100.T14 (IO_L51P_M1DQ12_1), U200.G6 (DQ7)
/ram/RAM_DQ8: U100.K15 (IO_L44P_A3_M1DQ6_1), U200.B1 (DQ8)
/ram/RAM_DQ9: U100.M16 (IO_L46N_FOE_B_M1DQ3_1), U200.C1 (DQ9)
/ram/RAM_DQ10: U100.L16 (IO_L47N_LDC_M1DQ1_1), U200.C2 (DQ10)
/ram/RAM_DQ11: U100.M15 (IO_L46P_FCS_B_M1DQ2_1), U200.D2 (DQ11)
/ram/RAM_DQ12: U100.N16 (IO_L45N_A0_M1LDQSN_1), U200.E2 (DQ12)
/ram/RAM_DQ13: U100.P16 (IO_L48N_M1DQ9_1), U200.F2 (DQ13)
/ram/RAM_DQ14: U100.N14 (IO_L45P_A1_M1LDQS_1), U200.F1 (DQ14)
/ram/RAM_DQ15: U100.P15 (IO_L48P_HDC_M1DQ8_1), U200.G1 (DQ15)
/ram/RAM_LB_N: U100.J16 (IO_L43N_GCLK4_M1DQ5_1), U200.A1 (~LB)
/ram/RAM_OE_N: U100.H15 (IO_L37P_A7_M1A0_1), U200.A2 (~OE)
/ram/RAM_UB_N: U100.K16 (IO_L44N_A2_M1DQ7_1), U200.B2 (~UB)
/ram/RAM_WE_N: U100.R14 (IO_L50P_M1UDQS_1), U200.G5 (~WE)
/ram/RAM_ZZ_N: U100.D16 (IO_L31N_A18_M1A12_1), U200.A6 (~ZZ)
GND: C120.2, C121.2, C122.2, C123.1, C124.1, C125.1, C200.2, C201.2, R116.1, U200.D1 (VSSQ), U200.E6 (VSS); also elsewhere on the board
LCD_CLK: U100.C11 (IO_L39P_0); also elsewhere on the board
LCD_D0: U100.C13 (IO_L63P_SCP7_0); also elsewhere on the board
LCD_D1: U100.B14 (IO_L65P_SCP3_0); also elsewhere on the board
LCD_D2: U100.A12 (IO_L62N_VREF_0); also elsewhere on the board
LCD_D4: U100.A11 (IO_L39N_0); also elsewhere on the board
LCD_D5: U100.B12 (IO_L62P_0); also elsewhere on the board
LCD_D6: U100.C10 (IO_L37N_GCLK12_0); also elsewhere on the board
LCD_D7: U100.A10 (IO_L35N_GCLK16_0); also elsewhere on the board
LCD_D8: U100.B10 (IO_L35P_GCLK17_0); also elsewhere on the board
LCD_D9: U100.A9 (IO_L34N_GCLK18_0); also elsewhere on the board
LCD_D10: U100.F9 (IO_L40P_0); also elsewhere on the board
LCD_D11: U100.A8 (IO_L33N_0); also elsewhere on the board
LCD_D12: U100.B8 (IO_L33P_0); also elsewhere on the board
LCD_D13: U100.A7 (IO_L6N_0); also elsewhere on the board
LCD_D14: U100.B6 (IO_L4P_0); also elsewhere on the board
LCD_D15: U100.A6 (IO_L4N_0); also elsewhere on the board
LCD_D16: U100.B5 (IO_L2P_0); also elsewhere on the board
LCD_D17: U100.A5 (IO_L2N_0); also elsewhere on the board
LCD_DE: U100.D11 (IO_L66P_SCP1_0); also elsewhere on the board
LCD_PCLK: U100.D9 (IO_L40N_0); also elsewhere on the board
LCD_TE: U100.A14 (IO_L65N_SCP2_0); also elsewhere on the board
LCD_VS: U100.E11 (IO_L64N_SCP4_0); also elsewhere on the board
unnamed: R116.2, U100.C4 (IO_L1P_HSWAPEN_0)
SD_CLK: U100.D6 (IO_L7P_0); also elsewhere on the board
SD_CMD: U100.C6 (IO_L7N_0); also elsewhere on the board
SD_D0: U100.C5 (IO_L3N_0); also elsewhere on the board
SD_D1: U100.D5 (IO_L3P_0); also elsewhere on the board
SD_D2: U100.D8 (IO_L38P_0); also elsewhere on the board
SD_D3: U100.C7 (IO_L6P_0); also elsewhere on the board

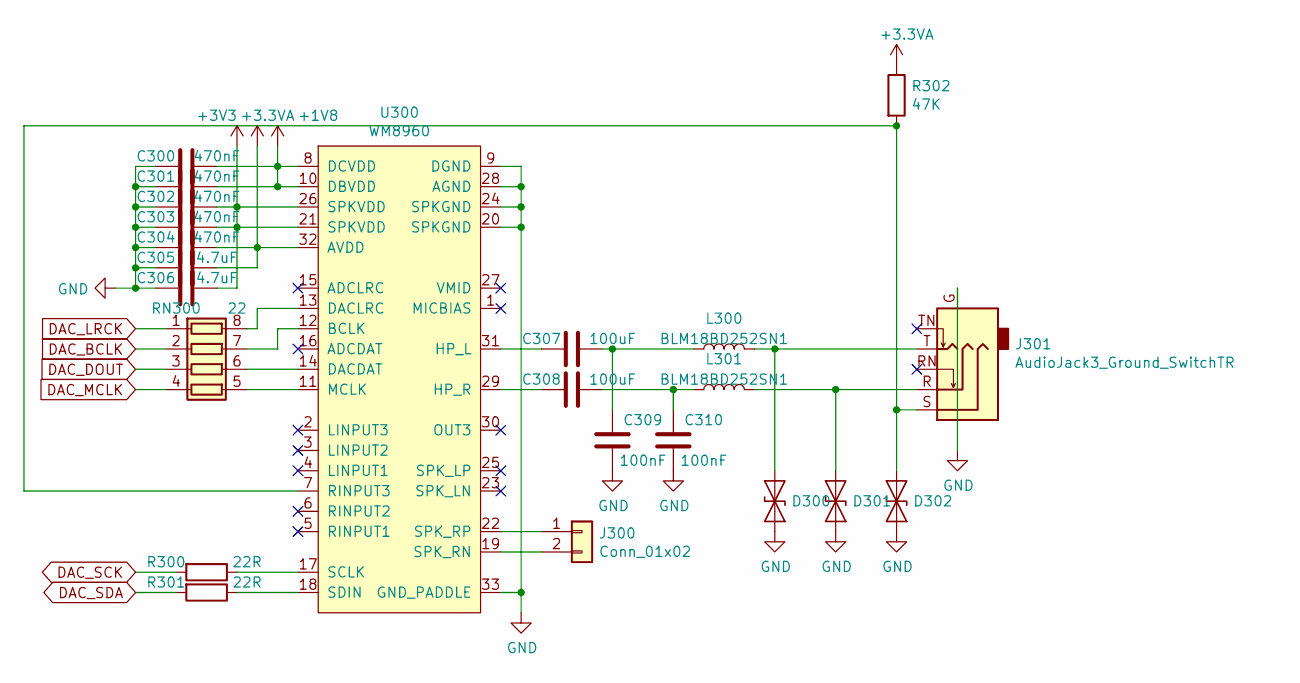
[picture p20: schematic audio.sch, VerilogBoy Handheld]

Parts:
C300, C301, C302, C303, C304: 470nF; C_0402_1005Metric
C305, C306: 4.7uF; C_0603_1608Metric
C307, C308: 100uF; C_1206_3216Metric
C309, C310: 100nF; C_0402_1005Metric
D300, D301, D302: ESD5B5.0ST1G; D_SOD-523
J300: Conn_01x02; PinHeader_1x02_P2.00mm_Vertical
J301: AudioJack3_Ground_SwitchTR; PJ-327E
L300, L301: BLM18BD252SN1; L_0603_1608Metric
R300, R301: 22R; R_0402_1005Metric
R302: 47K; R_0402_1005Metric
RN300: 22; R_Array_Convex_4x0402
U300: WM8960; QFN-32-1EP_5x5mm_P0.5mm_EP3.6x3.6mm

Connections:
+1V8: C300.1, C301.1, U300.8 (DCVDD), U300.10 (DBVDD); also elsewhere on the board
+3.3VA: C304.1, C305.1, R302.1, U300.32 (AVDD); also elsewhere on the board
+3V3: C302.1, C303.1, C306.1, U300.21 (SPKVDD), U300.26 (SPKVDD); also elsewhere on the board
GND: C300.2, C301.2, C302.2, C303.2, C304.2, C305.2, C306.2, C309.1, C310.1, D300.2 (A2), D301.2 (A2), D302.2 (A2), J301.G, U300.9 (DGND), U300.20 (SPKGND), U300.24 (SPKGND), U300.28 (AGND), U300.33 (GND_PADDLE); also elsewhere on the board
unnamed: C307.1, U300.31 (HP_L)
unnamed: C307.2, C309.2, L300.1
unnamed: C308.1, U300.29 (HP_R)
unnamed: C308.2, C310.2, L301.1
unnamed: D300.1 (A1), J301.T, L300.2
unnamed: D301.1 (A1), J301.R, L301.2
unnamed: D302.1 (A1), J301.S, R302.2, U300.7 (RINPUT3)
unnamed: J300.1, U300.22 (SPK_RP)
unnamed: J300.2, U300.19 (SPK_RN)
unnamed: R300.1, U300.17 (SCLK)
unnamed: R301.1, U300.18 (SDIN)
unnamed: RN300.5 (R4.2), U300.11 (MCLK)
unnamed: RN300.6 (R3.2), U300.14 (DACDAT)
unnamed: RN300.7 (R2.2), U300.12 (BCLK)
unnamed: RN300.8 (R1.2), U300.13 (DACLRC)

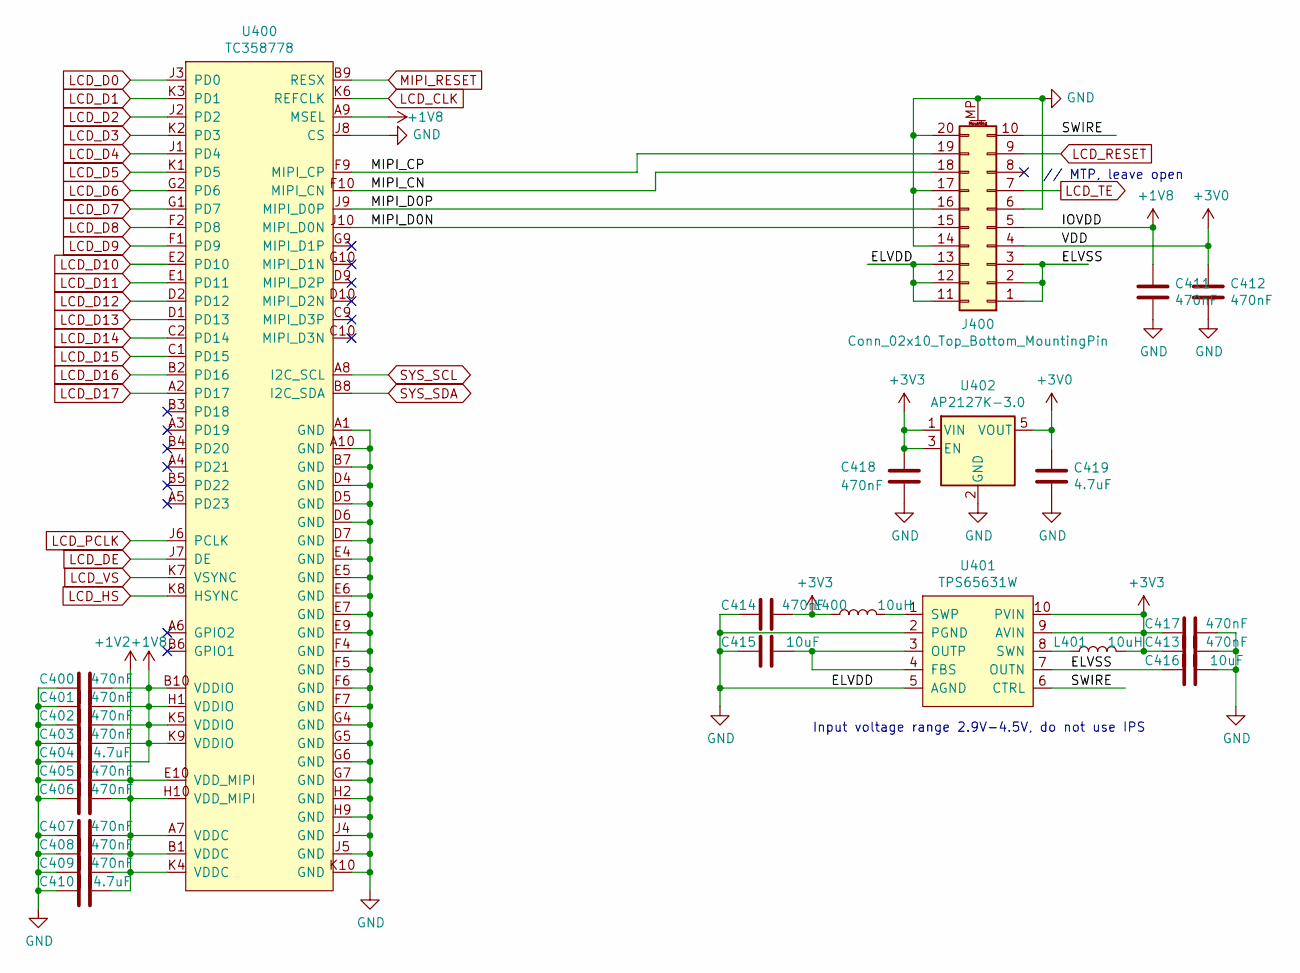
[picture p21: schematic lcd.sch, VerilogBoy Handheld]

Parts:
C400, C401, C402, C403, C405, C406, C407, C408, C409, C411, C412, C413, C414, C417, C418: 470nF; C_0402_1005Metric
C404, C410, C419: 4.7uF; C_0603_1608Metric
C415, C416: 10uF; C_0603_1608Metric
J400: Conn_02x10_Top_Bottom_MountingPin; AXE520124
L400, L401: 10uH; L_Vishay_IHLP-1212
U400: TC358778; BGA-80_10x10_7.0x7.0mm
U401: TPS65631W; DFN-10-1EP_3x3mm_P0.5mm_EP1.55x2.48mm
U402: AP2127K-3.0; SOT-23-5

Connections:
+1V2: C405.1, C406.1, C407.1, C408.1, C409.1, C410.1, U400.A7 (VDDC), U400.B1 (VDDC), U400.E10 (VDD_MIPI), U400.H10 (VDD_MIPI), U400.K4 (VDDC); also elsewhere on the board
+1V8: C400.1, C401.1, C402.1, C403.1, C404.1, C411.1, J400.5, U400.A9 (MSEL), U400.B10 (VDDIO), U400.H1 (VDDIO), U400.K5 (VDDIO), U400.K9 (VDDIO); also elsewhere on the board
+3V0: C412.1, C419.1, J400.4, U402.5 (VOUT)
+3V3: C413.2, C414.1, C417.2, C418.1, L400.1, L401.2, U401.9 (AVIN), U401.10 (PVIN), U402.1 (VIN), U402.3 (EN); also elsewhere on the board
/lcd/ELVSS: C416.2, J400.1, J400.2, J400.3, U401.7 (OUTN)
/lcd/MIPI_CN: J400.18, U400.F10 (MIPI_CN)
/lcd/MIPI_CP: J400.19, U400.F9 (MIPI_CP)
/lcd/MIPI_D0N: J400.15, U400.J10 (MIPI_D0N)
/lcd/MIPI_D0P: J400.16, U400.J9 (MIPI_D0P)
/lcd/SWIRE: J400.10, U401.6 (CTRL)
GND: C400.2, C401.2, C402.2, C403.2, C404.2, C405.2, C406.2, C407.2, C408.2, C409.2, C410.2, C411.2, C412.2, C413.1, C414.2, C415.2, C416.1, C417.1, C418.2, C419.2, J400.6, J400.11, J400.12, J400.13, J400.14, J400.17, J400.20, J400.MP (MountPin), U400.A1 (GND), U400.A10 (GND), U400.B7 (GND), U400.D4 (GND), U400.D5 (GND), U400.D6 (GND), U400.D7 (GND), U400.E4 (GND), U400.E5 (GND), U400.E6 (GND), U400.E7 (GND), U400.E9 (GND), U400.F4 (GND), U400.F5 (GND), U400.F6 (GND), U400.F7 (GND), U400.G4 (GND), U400.G5 (GND), U400.G6 (GND), U400.G7 (GND), U400.H2 (GND), U400.H9 (GND), U400.J4 (GND), U400.J5 (GND), U400.J8 (CS), U400.K10 (GND), U401.2 (PGND), U401.5 (AGND), U402.2 (GND); also elsewhere on the board
LCD_CLK: U400.K6 (REFCLK); also elsewhere on the board
LCD_D0: U400.J3 (PD0); also elsewhere on the board
LCD_D1: U400.K3 (PD1); also elsewhere on the board
LCD_D2: U400.J2 (PD2); also elsewhere on the board
LCD_D4: U400.J1 (PD4); also elsewhere on the board
LCD_D5: U400.K1 (PD5); also elsewhere on the board
LCD_D6: U400.G2 (PD6); also elsewhere on the board
LCD_D7: U400.G1 (PD7); also elsewhere on the board
LCD_D8: U400.F2 (PD8); also elsewhere on the board
LCD_D9: U400.F1 (PD9); also elsewhere on the board
LCD_D10: U400.E2 (PD10); also elsewhere on the board
LCD_D11: U400.E1 (PD11); also elsewhere on the board
LCD_D12: U400.D2 (PD12); also elsewhere on the board
LCD_D13: U400.D1 (PD13); also elsewhere on the board
LCD_D14: U400.C2 (PD14); also elsewhere on the board
LCD_D15: U400.C1 (PD15); also elsewhere on the board
LCD_D16: U400.B2 (PD16); also elsewhere on the board
LCD_D17: U400.A2 (PD17); also elsewhere on the board
LCD_DE: U400.J7 (DE); also elsewhere on the board
LCD_PCLK: U400.J6 (PCLK); also elsewhere on the board
LCD_RESET: J400.9; also elsewhere on the board
LCD_TE: J400.7; also elsewhere on the board
LCD_VS: U400.K7 (VSYNC); also elsewhere on the board
unnamed: C415.1, U401.3 (OUTP), U401.4 (FBS)
unnamed: L400.2, U401.1 (SWP)
unnamed: L401.1, U401.8 (SWN)
SYS_SCL: U400.A8 (I2C_SCL); also elsewhere on the board
SYS_SDA: U400.B8 (I2C_SDA); also elsewhere on the board

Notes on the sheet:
Input voltage range 2.9V-4.5V, do not use IPS
// MTP, leave open

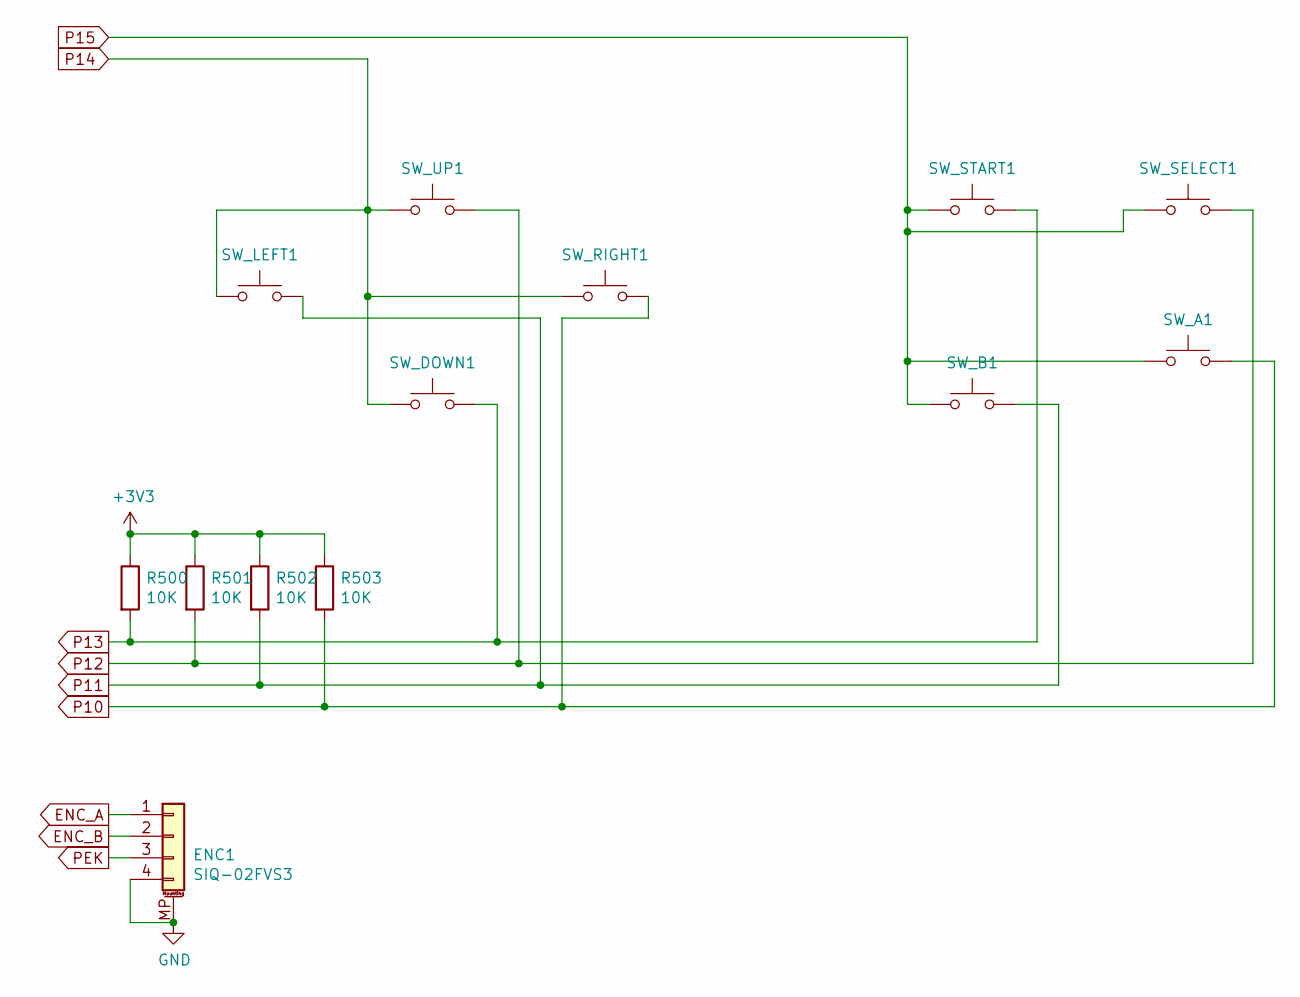
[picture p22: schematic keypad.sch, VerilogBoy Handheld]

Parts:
ENC1: SIQ-02FVS3
R500, R501, R502, R503: 10K; R_0402_1005Metric
SW_A1: SW_Push; Contact_4mm
SW_B1: SW_Push; Contact_4mm
SW_DOWN1: SW_Push; Contact_4mm
SW_LEFT1: SW_Push; Contact_4mm
SW_RIGHT1: SW_Push; Contact_4mm
SW_SELECT1: SW_Push; Contact_4mm
SW_START1: SW_Push; Contact_4mm
SW_UP1: SW_Push; Contact_4mm

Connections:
+3V3: R500.1, R501.1, R502.1, R503.1; also elsewhere on the board
ENC_A: ENC1.1; also elsewhere on the board
ENC_B: ENC1.2; also elsewhere on the board
GND: ENC1.4, ENC1.MP (MountPin); also elsewhere on the board
P10: R503.2, SW_A1.2, SW_RIGHT1.2; also elsewhere on the board
P11: R502.2, SW_B1.2, SW_LEFT1.2; also elsewhere on the board
P12: R501.2, SW_SELECT1.2, SW_UP1.2; also elsewhere on the board
P13: R500.2, SW_DOWN1.2, SW_START1.2; also elsewhere on the board
P14: SW_DOWN1.1, SW_LEFT1.1, SW_RIGHT1.1, SW_UP1.1; also elsewhere on the board
P15: SW_A1.1, SW_B1.1, SW_SELECT1.1, SW_START1.1; also elsewhere on the board
PEK: ENC1.3; also elsewhere on the board

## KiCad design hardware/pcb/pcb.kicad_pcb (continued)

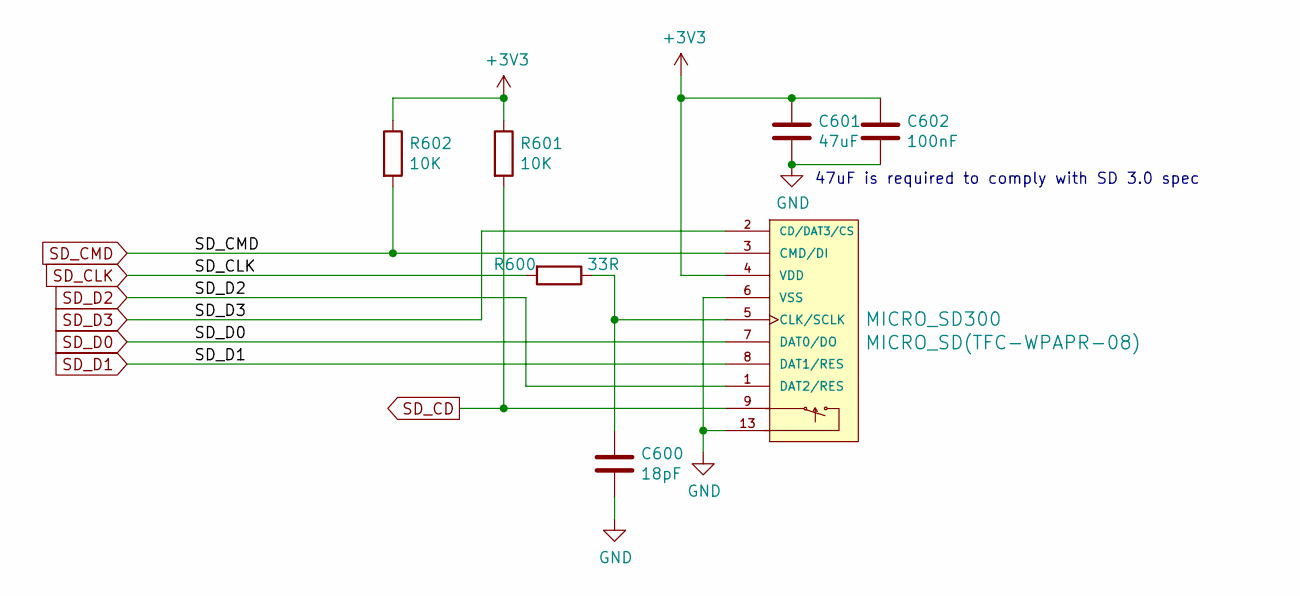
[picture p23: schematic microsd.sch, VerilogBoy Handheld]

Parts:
C600: 18pF; C_0402_1005Metric
C601: 47uF; C_0805_2012Metric
C602: 100nF; C_0402_1005Metric
MICRO_SD300: MICRO_SD(TFC-WPAPR-08); TFC-WPAPR-08
R600: 33R; R_0402_1005Metric
R601, R602: 10K; R_0402_1005Metric

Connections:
+3V3: C601.1, C602.1, MICRO_SD300.4 (VDD), R601.1, R602.1; also elsewhere on the board
GND: C600.2, C601.2, C602.2, MICRO_SD300.6 (VSS), MICRO_SD300.10, MICRO_SD300.11, MICRO_SD300.12, MICRO_SD300.13; also elsewhere on the board
unnamed: C600.1, MICRO_SD300.5 (CLK/SCLK), R600.1
SD_CD: MICRO_SD300.9, R601.2
SD_CLK: R600.2; also elsewhere on the board
SD_CMD: MICRO_SD300.3 (CMD/DI), R602.2; also elsewhere on the board
SD_D0: MICRO_SD300.7 (DAT0/DO); also elsewhere on the board
SD_D1: MICRO_SD300.8 (DAT1/RES); also elsewhere on the board
SD_D2: MICRO_SD300.1 (DAT2/RES); also elsewhere on the board
SD_D3: MICRO_SD300.2 (CD/DAT3/CS); also elsewhere on the board

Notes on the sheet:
47uF is required to comply with SD 3.0 spec

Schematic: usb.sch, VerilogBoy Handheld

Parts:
C700: 10uF; C_0603_1608Metric
C701: 100nF; C_0805_2012Metric
D700: B72590D0050H160; D_0402_1005Metric
J700: USB_B_Micro; USB_Micro-B_Amphenol_10103594-0001LF_Horizontal
R700: 1R; R_0603_1608Metric
R701: 0; R_0805_2012Metric
U700: USBLC6-2SC6; SOT-23-6

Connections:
GND: C701.2, D700.2 (A2), R700.2, R701.2, U700.2 (GND); also elsewhere on the board
unnamed: C700.2, R700.1
unnamed: C701.1, J700.5 (GND), J700.6 (Shield), R701.1
USB_DM: J700.2 (D-), U700.1 (IO1), U700.6 (IO1); also elsewhere on the board
USB_DP: J700.3 (D+), U700.3 (IO2), U700.4 (IO2); also elsewhere on the board
VBUS: C700.1, D700.1 (A1), J700.1 (VBUS); also elsewhere on the board

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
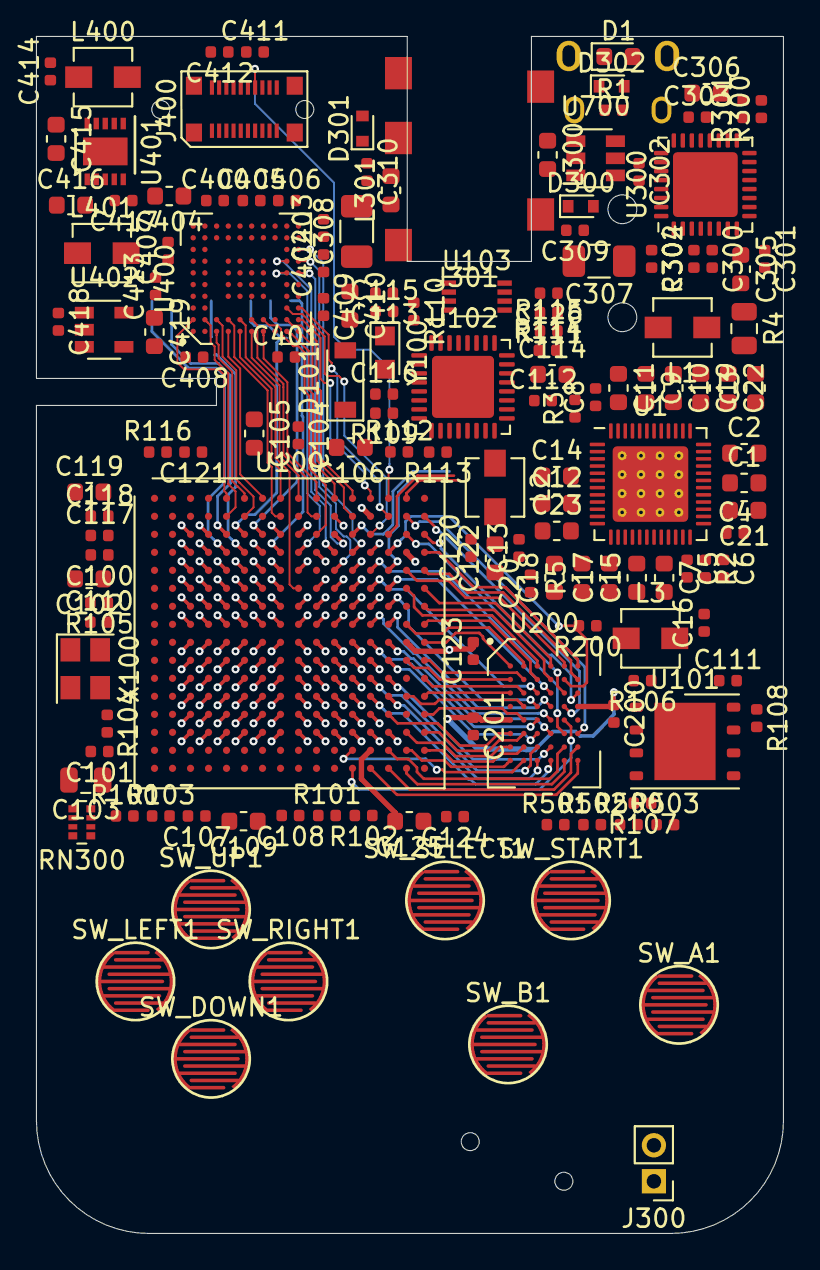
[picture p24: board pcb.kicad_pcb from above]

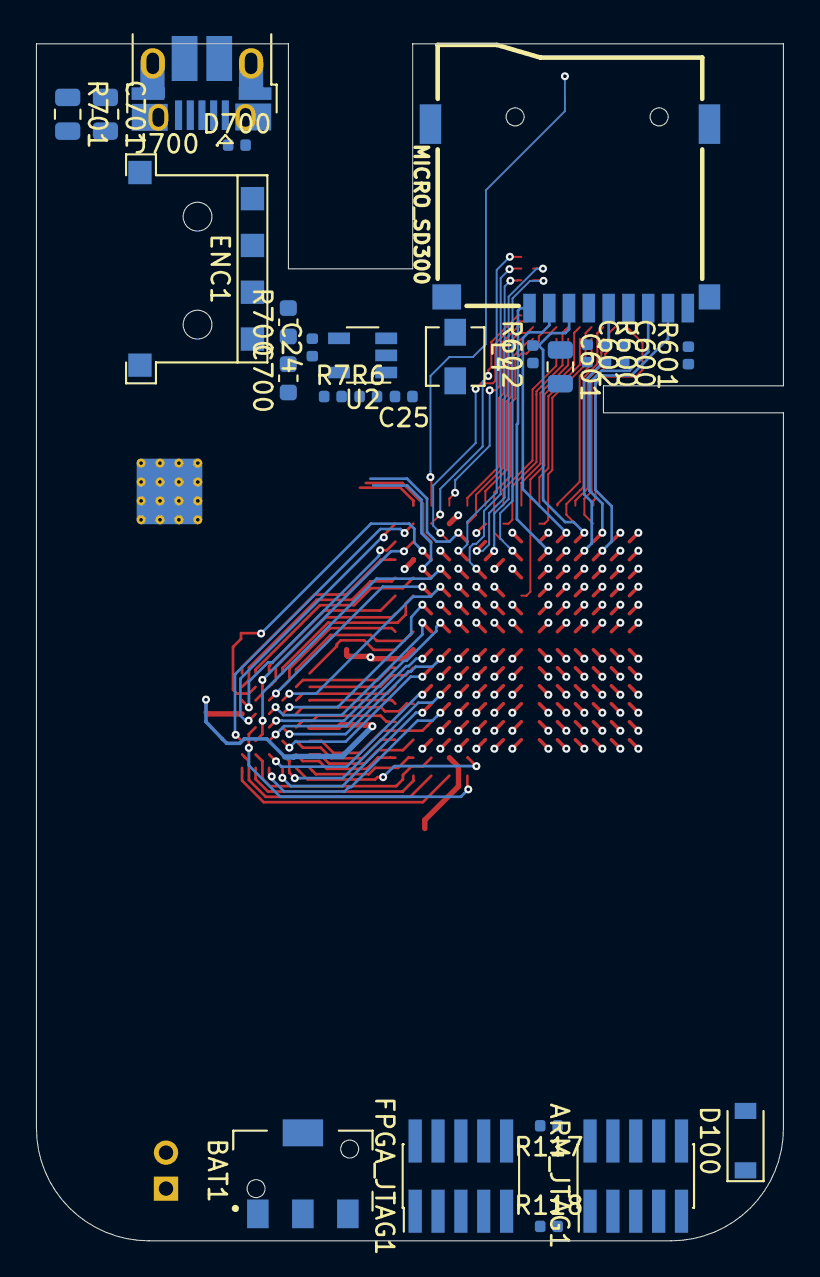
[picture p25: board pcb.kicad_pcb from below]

Board: 4 copper layers, 41.5 x 66.5 mm, 176 parts (26 on the bottom side), 179 nets.

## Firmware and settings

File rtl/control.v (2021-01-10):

`timescale 1ns / 1ps
`default_nettype wire
`include "common.v"
//////////////////////////////////////////////////////////////////////////////////
// Company: 
// Engineer: Wenting Zhang
// 
// Module Name:    control
// Project Name:   VerilogBoy
// Description: 
//   The control unit of Game Boy CPU.
// Dependencies: 
// 
// Additional Comments: 
//   
//////////////////////////////////////////////////////////////////////////////////

module control(
    input        clk,
    input        rst,
    input  [7:0] opcode_early,
    /* verilator lint_off UNUSED */
    input  [7:0] imm,
    /* verilator lint_on UNUSED */
    input  [7:0] cb,
    input  [2:0] m_cycle_early,
    input  [1:0] ct_state,
    input        f_z,
    input        f_c,
    output reg [1:0] alu_src_a,
    output reg [2:0] alu_src_b,
    output reg       alu_src_xchg,
    output reg [1:0] alu_op_prefix,
    output reg [1:0] alu_op_src,
    output reg       alu_op_signed,
    output reg [1:0] alu_dst,
    output reg [1:0] pc_src,
    output reg       pc_we,
    output reg       pc_b_sel,
    output reg       pc_jr,
    output reg       pc_revert,
    output reg [2:0] rf_wr_sel,
    output reg [2:0] rf_rd_sel,
    output reg [1:0] rf_rdw_sel,
    output reg       temp_redir,
    output reg       opcode_redir,
    output reg [1:0] bus_op,
    output reg [1:0] db_src,
    output reg [1:0] ab_src,
    output reg [1:0] ct_op,
    output reg       flags_we,
    output reg [1:0] flags_pattern,
    output reg       high_mask,
    output           int_master_en,
    input            int_dispatch,
    output reg       int_ack,
    output reg       next,
    output reg       stop,
    output reg       halt,
    input            wake,
    output reg       fault
    );

    // Comb signal generated by control logic
    reg ime_clear;
    reg ime_set;
    reg ime_delay_set;
    // FF
    reg ime_delay_set_ff;
    reg ime;
    assign int_master_en = ime;

    wire [7:0] opcode = opcode_early;
    wire [2:0] m_cycle = m_cycle_early;

    always @(posedge clk)
        if (ct_state == 2'd2)
            ime_delay_set_ff <= ime_delay_set;

    always @(posedge clk) begin
        if (rst)
            ime <= 1'b0;
        else if (ime_clear)
            ime <= 1'b0;
        else if (ime_set)
            ime <= 1'b1;
        else if (ime_delay_set_ff)
            ime <= 1'b1;
    end

    reg halt_last;
    reg stop_last;
    reg fault_last;
    always @(posedge clk) begin
        if (rst) begin
            halt_last <= 1'b0;
            stop_last <= 1'b0;
            fault_last <= 1'b0;
        end
        else begin
            halt_last <= halt;
            stop_last <= stop;
            fault_last <= fault;
        end
    end

    reg wake_by_int;
    always @(posedge clk) begin
        if (rst)
            wake_by_int <= 1'b0;
        else begin
            if (int_dispatch && (m_cycle == 0)) begin
                wake_by_int <= wake;
            end
        end
    end

    // Combinational control signal
    reg [1:0] comb_alu_src_a;
    reg [2:0] comb_alu_src_b;
    reg       comb_alu_src_xchg;
    reg [1:0] comb_alu_op_prefix;
    reg [1:0] comb_alu_op_src;
    reg       comb_alu_op_signed;
    reg [1:0] comb_alu_dst;
    reg [1:0] comb_pc_src;
    reg       comb_pc_we;
    reg       comb_pc_b_sel;
    reg       comb_pc_jr;
    reg       comb_pc_revert;
    reg [2:0] comb_rf_wr_sel;
    reg [2:0] comb_rf_rd_sel;
    reg [1:0] comb_rf_rdw_sel;
    reg       comb_temp_redir;
    reg       comb_opcode_redir;
    reg [1:0] comb_bus_op;
    reg [1:0] comb_db_src;
    reg [1:0] comb_ab_src;
    reg [1:0] comb_ct_op;
    reg       comb_flags_we;
    reg [1:0] comb_flags_pattern;
    reg       comb_high_mask;
    reg       comb_int_ack;
    reg       comb_next;
    reg       comb_stop;
    reg       comb_halt;
    reg       comb_fault;
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

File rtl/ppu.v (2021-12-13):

`timescale 1ns / 1ps
//////////////////////////////////////////////////////////////////////////////////
// Company: 
// Engineer: Wenting Zhang
// 
// Create Date:    18:48:36 02/14/2018 
// Design Name: 
// Module Name:    ppu 
// Project Name: 
// Target Devices: 
// Tool versions: 
// Description: 
//   GameBoy PPU
// Additional Comments: 
//   There are three hardware layers in the GameBoy PPU: Background, Window, and 
//   Object (or sprites).
//
//   Window will render above the background and the object can render above the
//   background or under the background. Each object have a priority bit to
//   indicate where it should be rendered.
//
//   Background, Window, and Object can be individually turned on or off. When 
//   nothing is turned on, it displays white.
//
//   The whole render logic does NOT require a scanline buffer to work, and it
//   runs at 4MHz (VRAM runs at 2MHz)
//
//   There are two main parts of the logic, implemented in a big FSM. The first
//   one is the fetch unit, and the other is the pixel FIFO.
//
//   The pixel FIFO shifts out one pixel when it contains more than 8 pixels, the 
//   fetch unit would generally render 8 pixels in 6 cycles (so 2 wait cycles are
//   inserted so they are in sync generally). When there is no enough pixels,
//   the FIFO would stop and wait for the fetch unit.
//
//   Windows Trigger is handled in the next state logic, there is a distinct state
//   for the PPU to switch from background rendering to window rendering (flush 
//   the fifo and add wait cycles.)
//
//   Object Trigger is handled in the state change block, in order to backup the 
//   previous state. Current RAM address is also backed up during the handling of
//   object rendering. Once all the objects at this position has been rendered,
//   the render state machine could be restored to its previous state.
//
//   The output pixel clock is the inverted main clock, which is the same as the
//   real Game Boy Pixel data would be put on the pixel bus on the negedge of 
//   clock, so the LCD would latch the data on the posedge. The original Game Boy
//   used a gated clock to control if output is valid. Since gated clock is not
//   recommend, I used a valid signal to indicate is output should be considered
//   valid.
//////////////////////////////////////////////////////////////////////////////////
`default_nettype wire
module ppu(
    input clk,
    input rst,
    // MMIO Bus, 0xFF40 - 0xFF4B, always visible to CPU
    input wire [15:0] mmio_a,
    output reg [7:0]  mmio_dout,
    input wire [7:0]  mmio_din,
    input wire        mmio_rd,
    input wire        mmio_wr,
    // VRAM Bus, 0x8000 - 0x9FFF
    input wire [15:0] vram_a,
    output wire [7:0] vram_dout,
    input wire [7:0]  vram_din,
    input wire        vram_rd,
    input wire        vram_wr,
    // OAM Bus,  0xFE00 - 0xFE9F
    input wire [15:0] oam_a,
    output wire [7:0] oam_dout,
    input wire [7:0]  oam_din,
    input wire        oam_rd,
    input wire        oam_wr,
    // Interrupt interface
    output reg int_vblank_req,
    output reg int_lcdc_req,
    input int_vblank_ack,
    input int_lcdc_ack,
    // Pixel output
    output cpl, // Pixel Clock, = ~clk
    output reg [1:0] pixel, // Pixel Output
    output reg valid, // Pixel Valid
    output reg hs, // Horizontal Sync, High Valid
    output reg vs, // Vertical Sync, High Valid
    //Debug output
    output [7:0] scx,
    output [7:0] scy,
    output [4:0] state
    );
    
    // Global Wires ?
    integer i;
    
    // PPU registers
    reg [7:0] reg_lcdc; //$FF40 LCD Control (R/W)
    reg [7:0] reg_stat; //$FF41 LCDC Status (R/W)
    reg [7:0] reg_scy;  //$FF42 Scroll Y (R/W)
    reg [7:0] reg_scx;  //$FF43 Scroll X (R/W)
    reg [7:0] reg_ly;   //$FF44 LCDC Y-Coordinate (R) Write will reset the counter
    reg [7:0] reg_dma;  //$FF46 DMA, actually handled outside of PPU for now
    reg [7:0] reg_lyc;  //$FF45 LY Compare (R/W)
    reg [7:0] reg_bgp;  //$FF47 BG Palette Data (R/W) Non-CGB mode only
    reg [7:0] reg_obp0; //$FF48 Object Palette 0 Data (R/W) Non-CGB mode only
    reg [7:0] reg_obp1; //$FF49 Object Palette 1 Data (R/W) Non-CGB mode only
    reg [7:0] reg_wy;   //$FF4A Window Y Position (R/W)
    reg [7:0] reg_wx;   //$FF4B Window X Position (R/W)
    
    // Some interrupt related register
    reg [7:0] reg_ly_last;
    reg [1:0] reg_mode_last; // Next mode based on next state
    
    wire reg_lcd_en = reg_lcdc[7];          //0=Off, 1=On
    wire reg_win_disp_sel = reg_lcdc[6];    //0=9800-9BFF, 1=9C00-9FFF
    wire reg_win_en = reg_lcdc[5];          //0=Off, 1=On
    wire reg_bg_win_data_sel = reg_lcdc[4]; //0=8800-97FF, 1=8000-8FFF
    wire reg_bg_disp_sel = reg_lcdc[3];     //0=9800-9BFF, 1=9C00-9FFF
    wire reg_obj_size = reg_lcdc[2];        //0=8x8, 1=8x16
    wire reg_obj_en = reg_lcdc[1];          //0=Off, 1=On
    wire reg_bg_disp = reg_lcdc[0];         //0=Off, 1=On
    wire reg_lyc_int = reg_stat[6];
    wire reg_oam_int = reg_stat[5];
    wire reg_vblank_int = reg_stat[4];
    wire reg_hblank_int = reg_stat[3];
    wire reg_coin_flag = reg_stat[2];
    wire [1:0] reg_mode = reg_stat[1:0];
    
    localparam PPU_MODE_H_BLANK    = 2'b00;
    localparam PPU_MODE_V_BLANK    = 2'b01;
    localparam PPU_MODE_OAM_SEARCH = 2'b10;
    localparam PPU_MODE_PIX_TRANS  = 2'b11;
    
    localparam PPU_PAL_BG  = 2'b00;
    localparam PPU_PAL_OB0 = 2'b01;
    localparam PPU_PAL_OB1 = 2'b10;
    
    reg [12:0] vram_addr_bg;
    reg [12:0] vram_addr_obj;
    wire [12:0] vram_addr_int;
    wire [12:0] vram_addr_ext;
    wire vram_addr_int_sel; // 0 - BG, 1 - OBJ
    
    assign vram_addr_int = (vram_addr_int_sel == 1'b1) ? (vram_addr_obj) : (vram_addr_bg);
    
    wire vram_access_ext = ((reg_mode == PPU_MODE_H_BLANK)||
                            (reg_mode == PPU_MODE_V_BLANK)||
                            (reg_mode == PPU_MODE_OAM_SEARCH));
    wire vram_access_int = ~vram_access_ext;
    wire oam_access_ext = ((reg_mode == PPU_MODE_H_BLANK)||
                           (reg_mode == PPU_MODE_V_BLANK));
    
    wire [12:0] window_map_addr = (reg_win_disp_sel) ? (13'h1C00) : (13'h1800);
    wire [12:0] bg_map_addr = (reg_bg_disp_sel) ? (13'h1C00) : (13'h1800);
    wire [12:0] bg_window_tile_addr = (reg_bg_win_data_sel) ? (13'h0000) : (13'h0800);
    
    // PPU Memories
    
    // 8 bit WR, 16 bit RD, 160Bytes OAM
    reg [7:0] oam_u [0: 79];
    reg [7:0] oam_l [0: 79];
    reg [7:0] oam_rd_addr_int;
    wire [7:0] oam_rd_addr;
    wire [7:0] oam_wr_addr;
    reg [15:0] oam_data_out;
    wire [7:0] oam_data_out_byte;
    wire [7:0] oam_data_in;
    wire oam_we;
    
    always @ (negedge clk)
    begin
        if (oam_we) begin
            if (oam_wr_addr[0])
                oam_u[oam_wr_addr[7:1]] <= oam_data_in;
            else
                oam_l[oam_wr_addr[7:1]] <= oam_data_in;
        end
        else begin
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

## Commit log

2018-02-09 Porting CPU and DMA
2018-02-14 Add chipscope and debug buttons
2018-02-18 Fix timing
    [vga_timing.xlsx]
2018-02-22 Fix DVI timing constraint error
    [vga_timing.xlsx]
2018-02-24 Implement PPU Interrupt
2018-03-03 Add null joystick & ppu enable bit bug fix
    [ppu.v]
2018-03-07 Implement OAM Search & Fix HV timing bug & Fix DVI timing bug & Implement #4
    [ppu.v]
2018-03-08 Fix PPU valid signal bug & Implement object rendering
    [ppu.v]
2018-03-15 Add support for SCX; Fix tile addressing bug
    [ppu.v]
2018-03-16 Make OAM ram seq write & seq read
    [vga_timing.xlsx]
2018-03-16 Fix pixel bit sequence bug
    [ppu.v]
2018-03-16 Fix background tile addressing
    [ppu.v]
2018-03-31 Start working on the target hardware
    [Schematic.sch]
2018-04-01 Initial layout
    [Schematic.sch]
2018-04-02 Add expansion riser connector
    [Schematic.sch]
2018-04-02 Add SD card slot
    [Schematic.sch]
2018-04-13 Implementing DualShock2 driver
2018-04-14 Support timer
2018-04-17 Dual Shock driver working
2018-04-18 Fix timer bug
2018-04-20 Fix sprite rendering overlap bug
    [ppu.v]
2018-04-20 Fix window trigger position bug
    [ppu.v]
2018-04-22 Fix timer interrupt bug
2018-04-22 Fix windows & object priority
    [ppu.v]
2018-04-22 Add wait cycle for DMA operation
2018-07-15 Clean up for refactoring
    [Schematic.sch, vga_timing.xlsx]
2018-07-16 initial framework
    [vga_timing.xlsx]
2018-08-01 hardware: start designing the hardware
    [Schematic.sch, VERILOGBOY.DSN]
2018-08-02 hardware: add pmu
    [VERILOGBOY.DSN]
2018-08-11 hardware: verify footprints
    [VERILOGBOY.DSN]
2018-10-14 hardware: working on 3d models
    [HY-TF1007B.STL, PJ-313D.STL, USBMicroF.STL]
2018-10-15 hardware: start designing case
    [assembly.SLDASM, bl_5c.SLDPRT, bp_6m.SLDPRT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]
2018-10-20 hardware: 3d model change
    [assembly.SLDASM, front_case.SLDPRT, pcb.SLDPRT]
2018-10-20 hardware: adjust placement
    [HY-TF1007B.SLDPRT, HY-TF1007B.STL, PJ-313D.SLDPRT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]
2018-10-21 hardware: finializing schematics
    [VERILOGBOY.DSN, VERILOGBOY.sch]
2018-10-22 hardware: initial pcb layout
    [Schematic.sch, VERILOGBOY.DSN]
2018-10-22 hardware: minor case design change
    [PJ-327F.SLDPRT, PJ-399B.SLDPRT, assembly.SLDASM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]
2018-10-26 hardware: add key foam support structure
    [front_case.SLDPRT]
2018-10-28 hardware: finish pcb rev 1
    [VERILOGBOY.DSN]
2018-10-28 hardware: update converted file
    [VERILOGBOY.sch]
2018-11-11 doc: handling multi-M-cycle instructions
    [control_unit.ods]
2018-11-18 doc: finish first cycle decoding table
    [control_unit.ods]
2018-11-21 doc: fix error & design change
    [control_unit.ods]
2018-11-21 rtl: implement more instructions & bug fixes
    [control.v]
2018-11-23 target-vb: basic framework & add axp driver
2018-11-24 target-vbh: implement mcu-fpga spi communication
2018-12-01 target-vb: add pwm driver
2018-12-06 target-vbh: implement mipi dsi driver
2018-12-09 Fix #12 Fix #11
    [VERILOGBOY.DSN]
2018-12-13 hardware: modify RAM connections
    [VERILOGBOY.DSN]
2018-12-21 hardware: pcb rev1a
    [VERILOGBOY.DSN]
2018-12-29 hardware: fix wrong inductor value
    [VERILOGBOY.DSN]
2019-01-02 rtl: fix 16bit imm loading
    [control_unit.ods]
2019-01-03 rtl: implement more instructions
    [control_unit.ods]
2019-01-13 rtl: handle jr/jp/call
    [control_unit.ods]
2019-01-19 rtl: fix ld, cb instructions
    [control.v]
2019-01-20 rtl: support ld a, [hl+/-], bug fixes
    [control_unit.ods]
2019-01-20 rtl: fix reg/wire definition errors
    [control.v]
2019-01-22 rtl: fix several instructions
    [control.v]
2019-01-22 rom: implement dsi driver
2019-01-25 bootrom: fix dsi driver
2019-01-27 rtl: support more instructions
    [control_unit.ods]
2019-02-03 hardware: fix #8 fix #6
    [VERILOGBOY.DSN]
2019-02-06 rtl: support interrupt
    [control_unit.ods]
2019-02-24 rtl: fix wrong reg/wire type
    [control.v]
2019-03-01 target-panog1: explicitly define wire type
2019-03-03 target-panog1: allow spi booting
2019-03-03 target-panog1/fw: support spi boot, add dhrystone test
2019-03-23 doc: update various documents
    [control_unit.ods]
2019-03-26 target-panog1: add simple uart tx
2019-03-28 target-panog1: implement usb gamepad driver; implement usb int xfer list
2019-03-29 rtl: fix sub instruction
    [control.v]
2019-03-29 sim: implement mmr probe; integrate dispsim
2019-03-30 rtl: bug fixes, mainly flags related
    [control.v]
2019-03-30 rtl: fix rst instruction
    [control_unit.ods]
2019-03-31 rtl: add bootrom and dma
2019-03-31 rtl: support timer
2019-04-07 target-panog1: use spi xip for rv fw
2019-04-10 rtl: fix dma timing issue
    [dma.v]
2019-04-12 cpu: fix interrupt dispatch
    [control.v]
2019-04-13 rtl: replace one halt bug with another halt bug
    [control.v]
2019-04-13 rtl: fix sprite display bug; fix various width bugs
    [control_unit.ods]
2019-04-16 rtl: fixed interrupt dispatch cancellation
2019-04-25 rtl: fix interrupt timing
    [control.v]
2019-08-12 USB fixes, now works with 3 devices it didn't work with before.
2019-08-12 Added support for programming SPI flash using xc3sprog. It's much faster than Impact since it can rewrite just the firmware image w/o rewritting the .bit image.
2019-08-18 Increased hub power on delay to 1.5 seconds, fixes another USB flash drive. On a normal full system the timing isn't critical since an attached device can connect at any time following initialization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
2020-01-06 vbh: migrate to kicad
    [VERILOGBOY.DSN, VERILOGBOY.sch, audio.sch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]
2020-01-07 vbh: pcb layout
    [audio.sch, keypad.sch, lcd.sch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]
2020-05-06 sim: allow instruction level trace
2020-05-06 rtl: remove decoder rom
    [control_unit.ods]
2020-06-06 rtl: control unit should respond to reset on any posedge of clock
    [control.v]
2020-06-06 rtl: fix mem to reg alu double writeback
    [control.v]
2020-06-07 rtl: fix flags update in mem to reg alu instructions
    [control.v]
2020-06-07 rtl: fix halt handling
    [control.v]
2020-06-10 pcb: working on ram/ lcd routing
    [audio.sch, pcb.kicad_pcb, ram.sch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]
2020-06-11 pcb: routing lcd section
    [pcb.kicad_pcb, ram.sch]
2021-01-10 rtl: fix various interrupt handling edge cases
    [control.v]
2021-01-10 rtl: use sync reset
    [control.v, dma.v, ppu.v]
2021-01-10 remove vbh related stuff, moved to another repo
    [HY-TF1007B.SLDPRT, PJ-313D.SLDPRT, PJ-327F.SLDPRT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]
2021-12-08 Fix PPU bug where PPU is supposed to enter mode 0 on disable
    [ppu.v]
